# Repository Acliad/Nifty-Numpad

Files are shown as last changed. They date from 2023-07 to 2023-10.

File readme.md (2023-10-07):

Nifty Numpad is a full sized numpad with an extra row and two extra columns of macro keys. It was created because I wanted a companion to my TKL keyboard for work. My main workflow involves heavy use of ECAD programs, so the design was tailored for that, but it is generic enough to be nice for many workflows! 

The main features are:
- Full sized numpad with row of macro/function keys on the top
- Two extra columns of macro keys
- Cherry MX style socketed switches
- Backlit keys
- 3D printable case (FDM or resin)

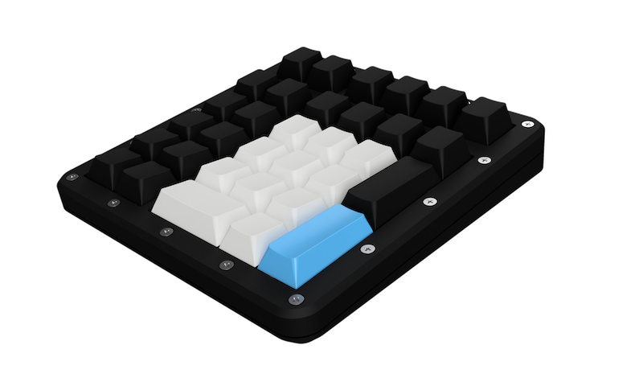
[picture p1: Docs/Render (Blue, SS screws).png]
render Render of Nifty Numpad


# Contents
- [Contents](#contents)
- [Building One](#building-one)
  - [1. PCB Assembly](#1-pcb-assembly)
  - [2. 3D Printed Case](#2-3d-printed-case)
  - [3. Switch Mounting Plate](#3-switch-mounting-plate)
  - [4. Switches/Keycaps](#4-switcheskeycaps)
  - [5. Software](#5-software)
- [TODO](#todo)
  - [Software](#software)
- [Changelog](#changelog)
  - [PCB](#pcb)
    - [Rev 1](#rev-1)
  - [Software](#software-1)
  - [Mechanical](#mechanical)

# Building One
All of the files needed to build this numpad are in this repo (with software as a submodule and in the main QMK repo). The total BOM cost will be somewhere around $65-$85 shipped, but depends heavily on where and how you source things like switches, keycaps, plate, etc. For example, I bought 120x switches, but if you could get 33 switches for cheaper, you might save ~$10. 

## 1. PCB Assembly
The most difficult part of the build is soldering the RP2040 (microcontroller used) and associated components. It is highly recommended that you have the PCBs assembled. The files are in this repo for getting the PCB assembled through JLC PCB. You may save some money by soldering some of the components yourself (especially the sockets and LEDs). However, if you just love to solder this can be done with a stencil and plenty of time. I should know 🥲

You can choose to omit the LEDs if you're not into that sort of thing. It'll save you a few bucks. 

Parts marked as (DNF) in the BOM are not meant to be populated. If you want easy debugging for software development, you can populate R103, SW101, and SW102.

To have the PCB assembled:
1. Upload the gerber files from PCB/Main PCB/production/Nifty_Numpad.zip to JLC PCB.
2. Check the PCB Assembly toggle on the JLC PCB order page.
   1. Choose the PCBA Type. If you want JLC to solder the LEDs and sockets for you, you need to choose Standard. Otherwise, choose economy. Economy is a bit cheaper.
3. On the PCB Assembly page, you will need to upload the bom.csv and positions.csv file from PCB/Main PCB/production/
4. On the Components Placements page, make sure all of the ICs are orientated correctly. They usually aren't by default since JLC's library orientation is generally different from KiCad's.

To Solder the PCB assembly yourself:
1. Order PCBs (I use JLC, you can use whomever you like).
2. Order a stencil (you can usually do this at the same time as the PCB).
3. Order parts (I have DigiKey PNs in the electrical BOM, but again feel free to substitute)
   - The switch sockets are not available on DigiKey. [I bought mine on Amazon](https://www.amazon.com/dp/B0BVH6M5FP?psc=1&ref=ppx_yo2ov_dt_b_product_details), but you can source them from most keyboard suppliers.
   - The LEDs come in packs of 10. You can get them from DigiKey or Adafruit, but note if you upload the BOM directly to DigiKey it will put in a quantity of 33, which is actually 330.
4. Solder it!
    - I recommend a reflow oven, but a hot air station or hot plate works too.

## 2. 3D Printed Case
This case was initially designed to be 3D printed on a resin printer, but it actually prints best on an FDM printer. There are not special instructions here. You can either print the case yourself or have it printed using a service. JLC offers printing of many varieties. This might be a good choice if you're already ordering the PCB from them.

All the screw holes are designed to be tapped by a self-tapping screw. The BOM has some recommendations for some plastic-threading screws. 

I have added a "[shadow line](https://www.youtube.com/watch?v=8dhFhU7Nl_0)" to the case outline. There's a top-case print option with and without this line. I think it helps the look a bit for FDM prints, but it's up to you. 

It helps the sound profile considerably to fill up the case with some kind of dampening material. You could use foam or pour castable silicone into the case (I used [this one](https://www.amazon.com/gp/product/B07V5FFPWC/ref=ppx_yo_dt_b_search_asin_title?ie=UTF8&psc=1)). You can (and probably should) pour the silicone directly into the case. However, I've also included a mold for this in the Mechanical folder.

## 3. Switch Mounting Plate
I used [plate-mount](https://switchandclick.com/plate-mounted-vs-pcb-mounted-keyboard/) switches on this design. You can either make your own plate or have one made for you. There's a model of the plate as well as a DXF file in the Mechanical folder. Here is some information about some options:

1. Order a plate out of FR-4 when you order the PCB
   - This is a good option if you're already ordering the PCB from JLC. You can order the plate at the same time and save on shipping. 
   - This plate is quite rigid and I've found it to work well.
2. Order or make a custom plate out of your preferred material.
    - If you have a laser cutter or CNC, you can use the DXF or step file to make a plate out of whatever material you like! Many people use plexilgass, but you could use wood or metal. 
3. Use the provided 3D model of the plate to 3D print a plate.
   - The plate works, but it's quite flimsy and makes taking all the switches off the PCB tedious

Whatever you choose to do, you should find appropriate files in the Mechanical folder.

## 4. Switches/Keycaps
The fun part! Choose your favorite Cherry MX compatible switches and pop them in. If you're using LEDs, make sure you get switches with a clear top. 

I found it difficult to source backlit keycaps that fit this build well. You might be better off using non-backlit keycaps. There are [some AliExpress sellers](https://www.aliexpress.us/item/3256801609324454.html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) who will sell portions of a keyboard at a time so you can mix and match colors. This is what I ended up doing, but I couldn't find any in a uniform profile like XDA or DSA. If you find a good source of keycaps, please share! 

If you're feeling plush, I think the numpad + icono kits of [these keycaps](https://drop.com/buy/drop-biip-mt3-extended-custom-keycap-set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) would be really nice. 

You'll also need 3x 2u plate-mount stabilizers. You can source these from most keyboard part suppliers or Ali Express.

## 5. Software
I've used [QMK](https://qmk.fm) for this build. Theere are builds for the [VIA](https://www.caniusevia.com) GUI configurator, a basic default usage, and an example for how to use the "fancy" RGB Idle mode and some tap-dance features. VIA is probably the easiest way to configure the keymap since you can configure it over a GUI, but if you're comfortable with QMK, you can do some cool customizations.

The Nifty Numpad has been merged into the main QMK repo, which you can find [here](https://github.com/qmk/qmk_firmware). My personal fork for developing the keyboard software is a submodule of this repo. You can find it [here](https://github.com/Acliad/qmk_firmware).

QMK and the build/flash process is pretty well document, so I'll leave that to the QMK community. If you have specific issues with the Nifty Numpad, feel free to message me. 

# TODO
## Software
- ~Implement VIAL for GUI remapping of buttons~
- ~Add other keymaps (an actual default and rename current to Cadence is a good start)~
- Create visual legend for RGB settings layer

# Changelog
## PCB
### Rev 1
- Changed footprint for W25Q40CLSNIG from wide to narrow footprint to match DigiKey PN
- Changed standoff holes to 6.0mm (from 4.6mm)
- Update LED footprint
- Add WASD graphic

## Software
- Added additional keymaps: default, VIA, and example. Old default moved to "Cadence" keymap
- Cleaned up code and file structure to align with QMK standards

## Mechanical
- Updated plate to use pan head screws
- Added clearance to top piece for pan head plate mount screws
- Moved "Designed By" tag to inside numpad
- Added a silicone sound dampening mold
- Added a "[shadow line](https://www.youtube.com/watch?v=8dhFhU7Nl_0)" model

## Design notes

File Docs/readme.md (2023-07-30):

Nifty Numpad is a full sized numpad with an extra row and two extra columns of macro keys. It was created because I wanted a companion to my TKL keyboard for work. My main workflow involves heavy use of ECAD programs, so the design was tailored for that, but it is generic enough to be nice for many workflows! 

The main features are:
- Full sized numpad with row of macro/function keys on the top
- Two extra columns of macro keys
- Cherry MX style socketed switches
- Backlit keys
- 3D printable case (FDM or resin)

render Render of Nifty Numpad

# Contents
- [Contents](#contents)
- [Building One](#building-one)
  - [1. PCB Assembly](#1-pcb-assembly)
  - [2. 3D Printed Case](#2-3d-printed-case)
  - [3. Switch Mounting Plate](#3-switch-mounting-plate)
  - [4. Switches/Keycaps](#4-switcheskeycaps)
  - [5. Software](#5-software)
- [TODO](#todo)
  - [Software](#software)
- [Changelog](#changelog)
  - [PCB](#pcb)
    - [Rev 1](#rev-1)
  - [Software](#software-1)
    - [Rev 1](#rev-1-1)
  - [Mechanical](#mechanical)
    - [Rev 1](#rev-1-2)

# Building One
All of the files needed to build this numpad should be in this repo (with software as a submodule). The total BOM cost will probably be somewhere around $55-$85 shipped, but depends heavily on where and how you source things like switches, keycaps, plate, etc. For example, I bought 120x switches, which is rolled into the $75 estimate. But if you could get 33 switches for cheaper, you might save ~$10. 

## 1. PCB Assembly
The most difficult part of the build is soldering the RP2040 (microcontroller used) and associated components. It is possible to at least all the difficult components–maybe all the components–assembled by JLC PCB. At this time, however, I have not done the work to make that a one-click purchase. If you would like to contribute, that would be very welcome! 🙂

That said, if you really would like one of these but can't or don't want to do the soldering, feel free to shoot me a message. 

If you do have experience with reflow soldering (using a stencil), this shouldn't be too difficult. The RP2040 and USB-C connectors can be a little finicky, but with enough flux, anything is possible. 

To create the PCB assembly:
1. Order PCBs (I use JLC, you can use whoever you like).
2. Order a stencil (you can usually do this at the same time as the PCB).
3. Order parts (I have DigiKey PNs in the electrical BOM, but again feel free to substitute)
   - The switch sockets are not available on DigiKey. [I bought mine on Amazon](https://www.amazon.com/dp/B0BVH6M5FP?psc=1&ref=ppx_yo2ov_dt_b_product_details), but you can source them from most keyboard suppliers.
   - The LEDs come in packs of 10. You can get them from DigiKey or Adafruit, but note if you upload the BOM directly to DigiKey it will put in a quantity of 33, which is actually 330.
4. Solder it!
    - I recommend a reflow oven, but a hot air station or hot plate works too.

You can choose to omit the LEDs if you're not into that sort of thing. It'll save you a few bucks. 

Parts marked as (DNF) in the BOM are not meant to be populated. If you want easy debugging for software development, you can populate R103, SW101, and SW102.

## 2. 3D Printed Case
This case was initially designed to be 3D printed on a resin printer, but it actually prints best on an FDM printer. There are not special instructions here. You can either print the case yourself or have it printed using a service. JLC offers printing of many varieties. Might be a good choice if you're already ordering the PCB from them.

All the screw holes are designed to be tapped by a self-tapping screw. The BOM recommends some plastic-threading screws. 

I have added a "[shadow line](https://www.youtube.com/watch?v=8dhFhU7Nl_0)" to the case outline. There's a top-case print option with and without this line. I think it helps the look a bit for FDM prints, but it's up to you. 

## 3. Switch Mounting Plate
I used [plate-mount](https://switchandclick.com/plate-mounted-vs-pcb-mounted-keyboard/) switches on this design. There are services that will cut plate for you in various materials, but I've used flush mounted flat-head screws to secure the panel and the counter sink is an additional operation I don't think most services will do for you. These leaves at least three options:

1. Use the provided 3D model of the plate to 3D print a plate.
   - The plate works, but can be a bit flimsy and makes taking all the switches off the PCB tedious
2. Order or make a custom plate out of your preferred material and countersink the holes.
    - If you know what this means and are comfortable with a drill or drill press, it shouldn't be hard.
    - You could order the plate in FR4 from JLC at the same time you order the main PCB. If you end up making the KiCAD files for this, I'd love to add them to the repo. 
3. Modify the 3D model of the top piece to accommodate pan head screws. 
    - If you do this, I would love to add the file to the repo! It should be easy, I just don't have to time to print and verify right now.

Whatever you choose to do, you should find appropriate files in the Mechanical folder.

## 4. Switches/Keycaps
The fun part! Choose your favorite Cherry MX compatible switches and pop them in. If you're using LEDs, make sure you get switches with a clear top. 

I found it difficult to source backlit keycaps that fit this build well. You might be better off using non-backlit keycaps. There are [some AliExpress sellers](https://www.aliexpress.us/item/3256801609324454.html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) who will sell portions of a keyboard at a time so you can mix and match colors. This is what I ended up doing, but I couldn't find any in a uniform profile like XDA or DSA. If you find a good source of keycaps, please share! 

If you're feeling plush, I think the numpad + icono kits of [these keycaps](https://drop.com/buy/drop-biip-mt3-extended-custom-keycap-set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) would be really nice. 

You'll also need 3x 2u plate-mount stabilizers. You can source these from most keyboard part suppliers or Ali Express.

## 5. Software
I've used [QMK](https://qmk.fm) for this build. At the time of writing this, I only have one keymap that's pretty specialized to using Cadence PCB Allegro. However, it should be super easy to modify that keymap to fit your needs. I also plan on adding a better default mode and eventually implementing VIAL. Check the [TODO](#todo) list for planned updates. 

The Nifty Numpad hasn't been merged into the main QMK repo yet, so for now you can find it [here](https://github.com/Acliad/qmk_firmware). 

QMK and the build/flash process is pretty well document, so I'll leave that to the QMK community. If you have specific issues with the Nifty Numpad, feel free to message me. 

# TODO
## Software
- Implement VIAL for GUI remapping of buttons
- Add other keymaps (an actual default and rename current to Cadence is a good start)
- Create visual legend for RGB settings layer

# Changelog
## PCB
### Rev 1
- Changed footprint for W25Q40CLSNIG from wide to narrow footprint to match DigiKey PN
- Changed standoff holes to 6.0mm (from 4.6mm)
- Update LED footprint
- Add WASD graphic

## Software
### Rev 1
-

## Mechanical
### Rev 1
- Added a "[shadow line](https://www.youtube.com/watch?v=8dhFhU7Nl_0)" model

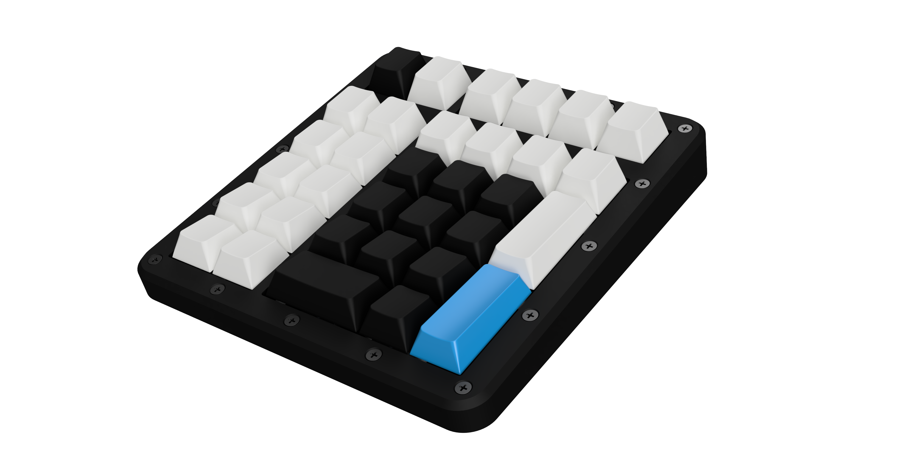
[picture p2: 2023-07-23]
Docs/Render (Black Oxide screws).png

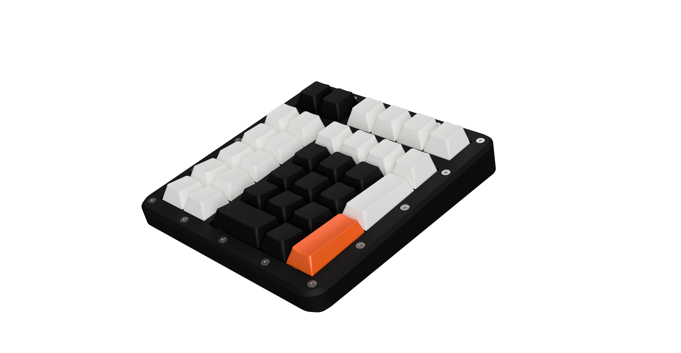
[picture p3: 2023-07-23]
Docs/Render (SS screws, orange).png

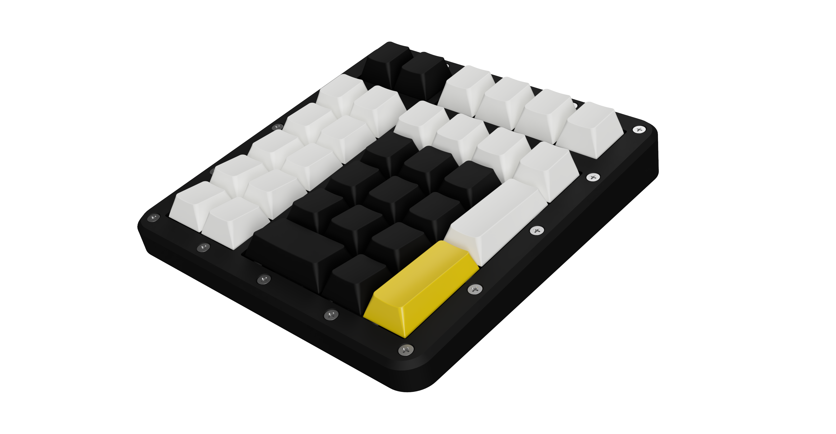
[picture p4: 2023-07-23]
Docs/Render (SS screws, yellow).png

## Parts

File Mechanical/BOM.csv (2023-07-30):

Part | Qty | Suggested Source | Comment
M2.6x10mm Plastic Tapping Screw | 16 | https://www.aliexpress.us/item/3256803049178065.html https://www.mcmaster.com/90485A432 | Use to screw top piece to base piece. You could get stainless or black depending on your preference. Note the McMaster Carr screws are actually M2.5; these are slightly smaller than the Ali Express screws and I have not tried them
M2.6x5mm Plastic Tapping Screw | 5 | https://www.aliexpress.us/item/3256803049178065.html https://www.mcmaster.com/90485A428 | Use to screw plate/PCB to base piece. You could get stainless or black depending on your preference. Note the McMaster Carr screws are actually M2.5; these are slightly smaller than the Ali Express screws and I have not tried them
Rubber Feet | 4 | https://www.mcmaster.com/95495K15/ | Attach to bottom of base
Mounting Plate | 1 | 3D Print | See the readme for more details
PCB Assembly | 1 | JLC PCB and self assembly | See the electrical BOM and readme for more details
Switches | 33 | Microcenter Any keyboard part supplier | Use your favorite Cherry MX compatible switches. Microcenter tends to have good prices on these if you have a local store. Make sure you get ones with a clear top if you're using the LEDs!
Keycaps | 33 | https://www.aliexpress.us/item/3256801609324454.html | You’ll have more options if you don’t look for backlit keycaps, but choose what you want!
2u Plate-mount Stabilizers | 3 | https://www.aliexpress.us/item/3256801595153884.html?curPageLogUid=UpkIp3myNO7D https://www.amazon.com/dp/B0978PWJG9?psc=1&ref=ppx_yo2ov_dt_b_product_details | These are also pretty generic and available from most keyboard parts suppliers. This design uses plate-mount stabs without the nubs on the bottom (but you can always clip these off).

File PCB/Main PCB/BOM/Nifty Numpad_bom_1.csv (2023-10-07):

References | Value | LCSC | DigiKey PN | Quantity Per PCB | Footprint | Datasheet
C118-C119 | 27pF | C107045 | 1276-2247-1-ND | 2 | C_0603_1608Metric | ~
C104-C114, C117, C201-C233 | 100nF | C14663 | 1276-1006-1-ND | 45 | C_0603_1608Metric | ~
C102-C103, C115-C116 | 1uF | C15849 | 1276-6524-1-ND | 4 | C_0603_1608Metric | ~
C101 | 10uF | C19702 | 490-10475-1-ND | 1 | C_0603_1608Metric | ~
D301-D333 | 1N4148 | C444720 | 4530-1N4148WCT-ND | 33 | D_SOD-123 | https://media.digikey.com/pdf/Data%20Sheets/Anbon%20Semi%20PDFs/1N4148W.pdf
D201-D233 | SK6805MINI-E | C5149201 | 1528-4960-ND | 33 | LED_SK6812-E_3.2x2.8mm | https://cdn-shop.adafruit.com/product-files/4960/4960_SK6812MINI-E_REV02_EN.pdf
J101 | SWD | C492404 | 2057-PH1-05-UA-ND | 1 (DNF) | PinHeader_1x05_P2.54mm_Vertical | ~
J103 | UART | C2691448 | 2057-PH1-04-UA-ND | 1 (DNF) | PinHeader_1x04_P2.54mm_Vertical | ~
J102 | USB-C | C2927038 | 2073-USB4105-GF-A-060CT-ND | 1 | USB_C_Receptacle_GCT_USB4105-GF-A-060 | https://www.usb.org/sites/default/files/documents/usb_type-c.zip
R105-R106 | 27 | C25190 | CR0603-FX-27R0ELFCT-ND | 2 | R_0603_1608Metric | ~
R104 | 330 | C23138 | CR0603-FX-3300ELFCT-ND | 1 | R_0603_1608Metric | ~
R103 | 1k | C21190 | RNCP0603FTD1K00CT-ND | 1 (DNF) | R_0603_1608Metric | ~
R108 | 1k | C21190 | RNCP0603FTD1K00CT-ND | 1 | R_0603_1608Metric | ~
R101-R102 | 5.1k | C23186 | CR0603-FX-5101ELFCT-ND | 2 | R_0603_1608Metric | ~
R107 | 10k | C25804 | RNCP0603FTD1K00CT-ND | 1 | R_0603_1608Metric | ~
SW301-SW317, SW319-SW328, SW330-SW331, SW333 | PG1511 | C5156480 |  | 30 | SW_Hotswap_Kailh_MX_1.00u | https://www.kailhswitch.com/Content/upload/pdf/202215927/CPG151101S11-16.pdf?rnd=543
SW318, SW329 | PG1511 | C5156480 |  | 2 | SW_Hotswap_Kailh_MX_2.00u_90deg | https://www.kailhswitch.com/Content/upload/pdf/202215927/CPG151101S11-16.pdf?rnd=543
SW332 | PG1511 | C5156480 |  | 1 | SW_Hotswap_Kailh_MX_2.00u | https://www.kailhswitch.com/Content/upload/pdf/202215927/CPG151101S11-16.pdf?rnd=543
SW101-SW102 | PTS636 SL43 SMTR LFS | C2800576 | CKN12309-1-ND | 2 (DNF) | SW-PUSH-6x3.5mm_CK-PTS636SL43x_HandSolder | https://www.ckswitches.com/media/2779/pts636.pdf
U101 | 3.3V | C431682 | 576-3215-1-ND | 1 | SOT-353_SC-70-5 | http://ww1.microchip.com/downloads/en/DeviceDoc/mic5365.pdf
U102 | CM1213A−02Sx | C5359995 | CM1213A-02SROSCT-ND | 1 | SOT-143 | https://www.onsemi.com/pdf/datasheet/cm1213a-d.pdf
U104 | RP2040 | C2040 | 2648-SC0914(13)CT-ND | 1 | QFN-56-1EP_7x7mm_P0.4mm_EP3.2x3.2mm | https://datasheets.raspberrypi.com/rp2040/rp2040-datasheet.pdf
U103 | SN74LVC1T45DCK | C9382 | 31-74LVC1T45DW-7CT-ND | 1 | SOT-363_SC-70-6 | http://www.ti.com/lit/ds/symlink/sn74lvc1t45.pdf
U105 | W25Q40CLSNIG | C2641149 | W25Q40CLSNIG-ND | 1 | SOIC-8_3.9x4.9mm_P1.27mm | http://www.winbond.com/resource-files/w25q32jv%20revg%2003272018%20plus.pdf
Y101 | ABLS-12.000MHZ-B4-T | C596818 | 535-10218-1-ND | 1 | Crystal_SMD_HC49-SD | https://abracon.com/Resonators/ABLS.pdf

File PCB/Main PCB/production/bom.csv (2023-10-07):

Designator | Footprint | Quantity | Value | LCSC Part #
C101 | 0603 | 1 | 10uF | C19702
C102, C103, C115, C116 | 0603 | 4 | 1uF | C15849
C104, C105, C106, C107, C108, C109, C110, C111, C112, C113, C114, C117, C201, C202, C203, C204, C205, C206, C207, C208, C209, C210, C211, C212, C213, C214, C215, C216, C217, C218, C219, C220, C221, C222, C223, C224, C225, C226, C227, C228, C229, C230, C231, C232, C233 | 0603 | 45 | 100nF | C14663
C118, C119 | 0603 | 2 | 27pF | C107045
D201, D202, D203, D204, D205, D206, D207, D208, D209, D210, D211, D212, D213, D214, D215, D216, D217, D218, D219, D220, D221, D222, D223, D224, D225, D226, D227, D228, D229, D230, D231, D232, D233 | LED_SK6812MINI-E_3.2x2.8mm | 33 | SK6812MINI-E | C5149201
D301, D302, D303, D304, D305, D306, D307, D308, D309, D310, D311, D312, D313, D314, D315, D316, D317, D318, D319, D320, D321, D322, D323, D324, D325, D326, D327, D328, D329, D330, D331, D332, D333 | D_SOD-123 | 33 | 1N4148 | C444720
J101 | PinHeader_1x05_P2.54mm_Vertical | 1 | SWD | DNP
J102 | USB_C_Receptacle_GCT_USB4105-GF-A-060 | 1 | USB-C | C2927038
J103 | PinHeader_1x04_P2.54mm_Vertical | 1 | UART | DNP
R101, R102 | 0603 | 2 | 5.1k | C23186
R103 | 0603 | 1 | 1k | DNP
R104 | 0603 | 1 | 330 | C23138
R105, R106 | 0603 | 2 | 27 | C25190
R107 | 0603 | 1 | 10k | C25804
R108 | 0603 | 1 | 1k | C21190
SW101, SW102 | SW-PUSH-6x3.5mm_CK-PTS636SL43x_HandSolder | 2 | PTS636 SL43 SMTR LFS | DNP
SW301, SW302, SW303, SW304, SW305, SW306, SW307, SW308, SW309, SW310, SW311, SW312, SW313, SW314, SW315, SW316, SW317, SW319, SW320, SW321, SW322, SW323, SW324, SW325, SW326, SW327, SW328, SW330, SW331, SW333 | SW_Hotswap_Kailh_MX_1.00u | 30 | PG1511 | C5156480
SW318, SW329 | SW_Hotswap_Kailh_MX_2.00u_90deg | 2 | PG1511 | C5156480
SW332 | SW_Hotswap_Kailh_MX_2.00u | 1 | PG1511 | C5156480
U101 | SOT-353_SC-70-5 | 1 | 3.3V | C431682
U102 | SOT-143 | 1 | CM1213A−02Sx | C5359995
U103 | SOT-363_SC-70-6 | 1 | SN74LVC1T45DCK | C9382
U104 | QFN-56-1EP_7x7mm_P0.4mm_EP3.2x3.2mm | 1 | RP2040 | C2040
U105 | SOIC-8_3.9x4.9mm_P1.27mm | 1 | W25Q40CLSNIG | C2641149
Y101 | Crystal_SMD_HC49-SD | 1 | ABLS-12.000MHZ-B4-T | C596818

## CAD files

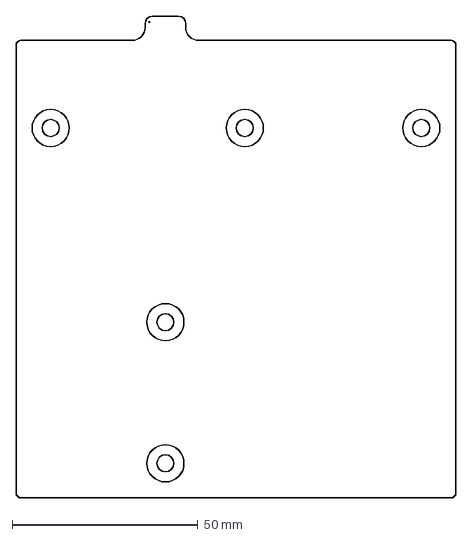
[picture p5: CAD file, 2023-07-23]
Mechanical/DXFs/PCB Outline.dxf
118.3 x 129.6 mm

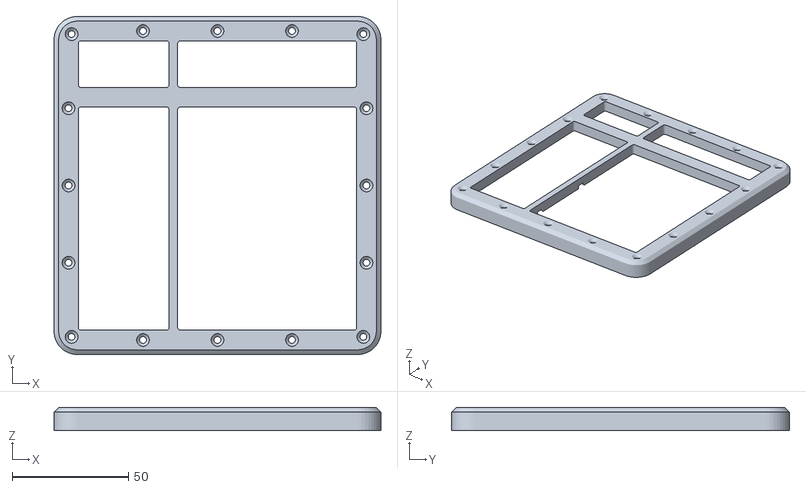
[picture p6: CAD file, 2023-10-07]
Mechanical/Meshes/Top_noShadowLine.stl
140.8 x 145.5 x 10.0

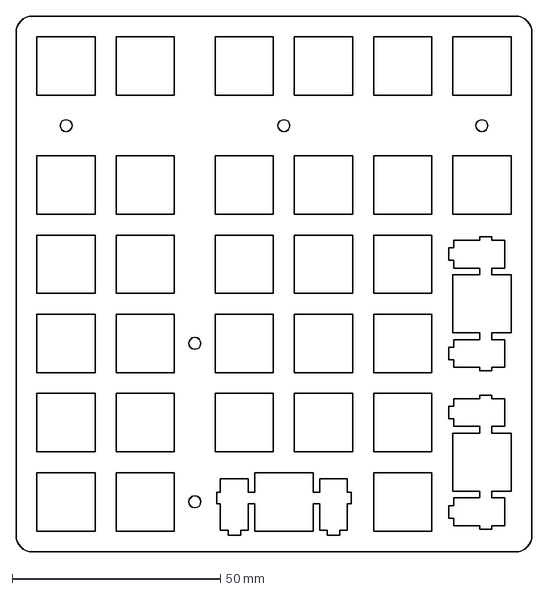
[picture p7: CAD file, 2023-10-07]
Mechanical/Plate Drawing.dxf
123.8 x 128.5 mm

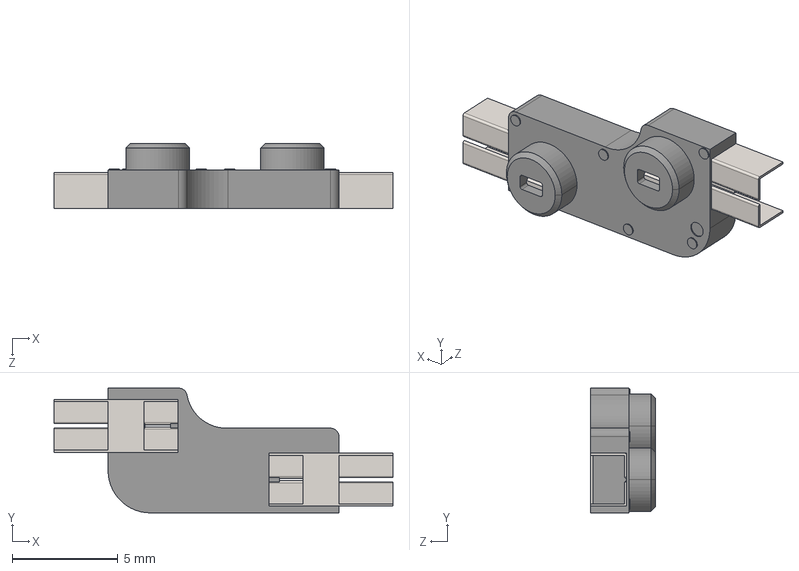
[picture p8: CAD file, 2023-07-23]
Mechanical/Solid/Kailh Hotswap MX.step
16.0 x 5.89 x 3.05 mm
Kailh Hotswap MX
Kailh Hotswap MX Inlay
Kailh Hotswap MX Inlay 2

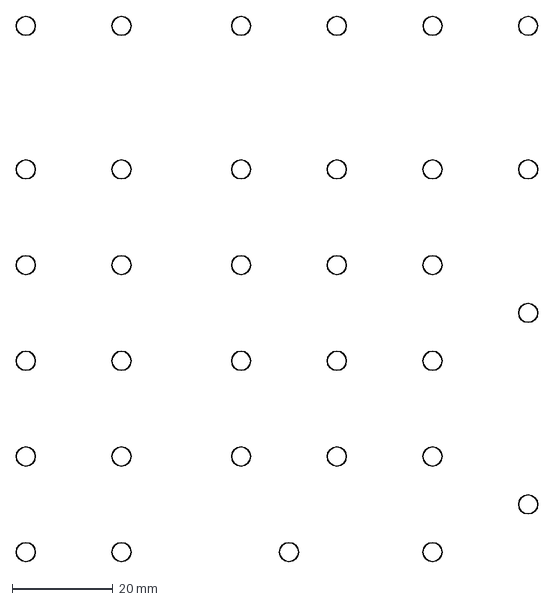
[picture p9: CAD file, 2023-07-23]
Mechanical/DXFs/PCB Switch Locations.dxf
103.6 x 108.3 mm

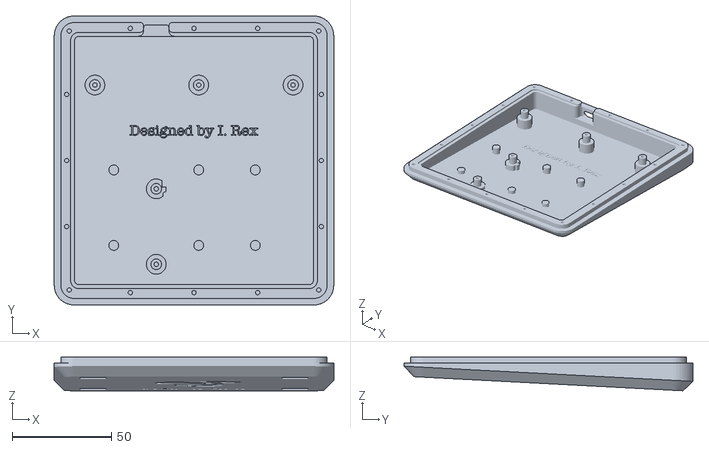
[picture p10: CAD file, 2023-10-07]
Mechanical/Meshes/Base.stl
140.8 x 145.5 x 16.9

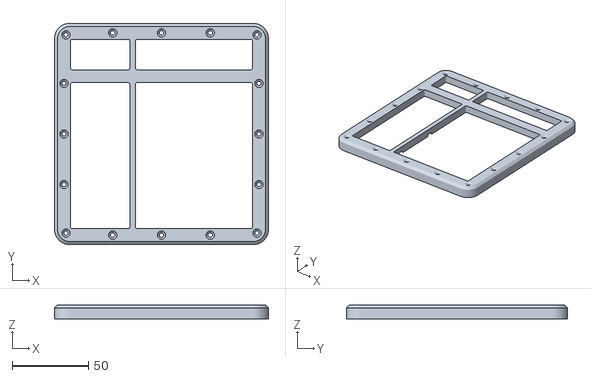
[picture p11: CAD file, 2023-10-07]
Mechanical/Meshes/Top.stl
140.8 x 145.5 x 9.30

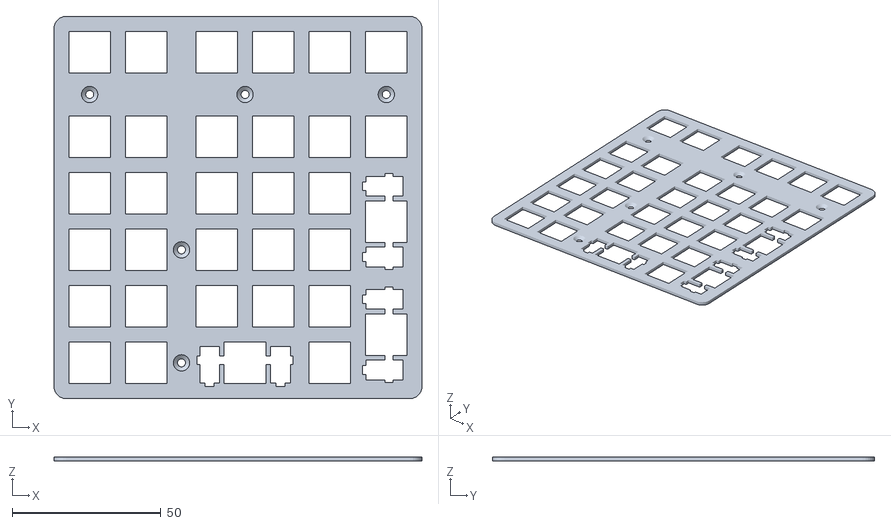
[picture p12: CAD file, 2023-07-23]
Mechanical/Meshes/Plate.stl
123.8 x 128.5 x 1.50

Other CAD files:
Mechanical/DXFs/Plate Drawing.dxf

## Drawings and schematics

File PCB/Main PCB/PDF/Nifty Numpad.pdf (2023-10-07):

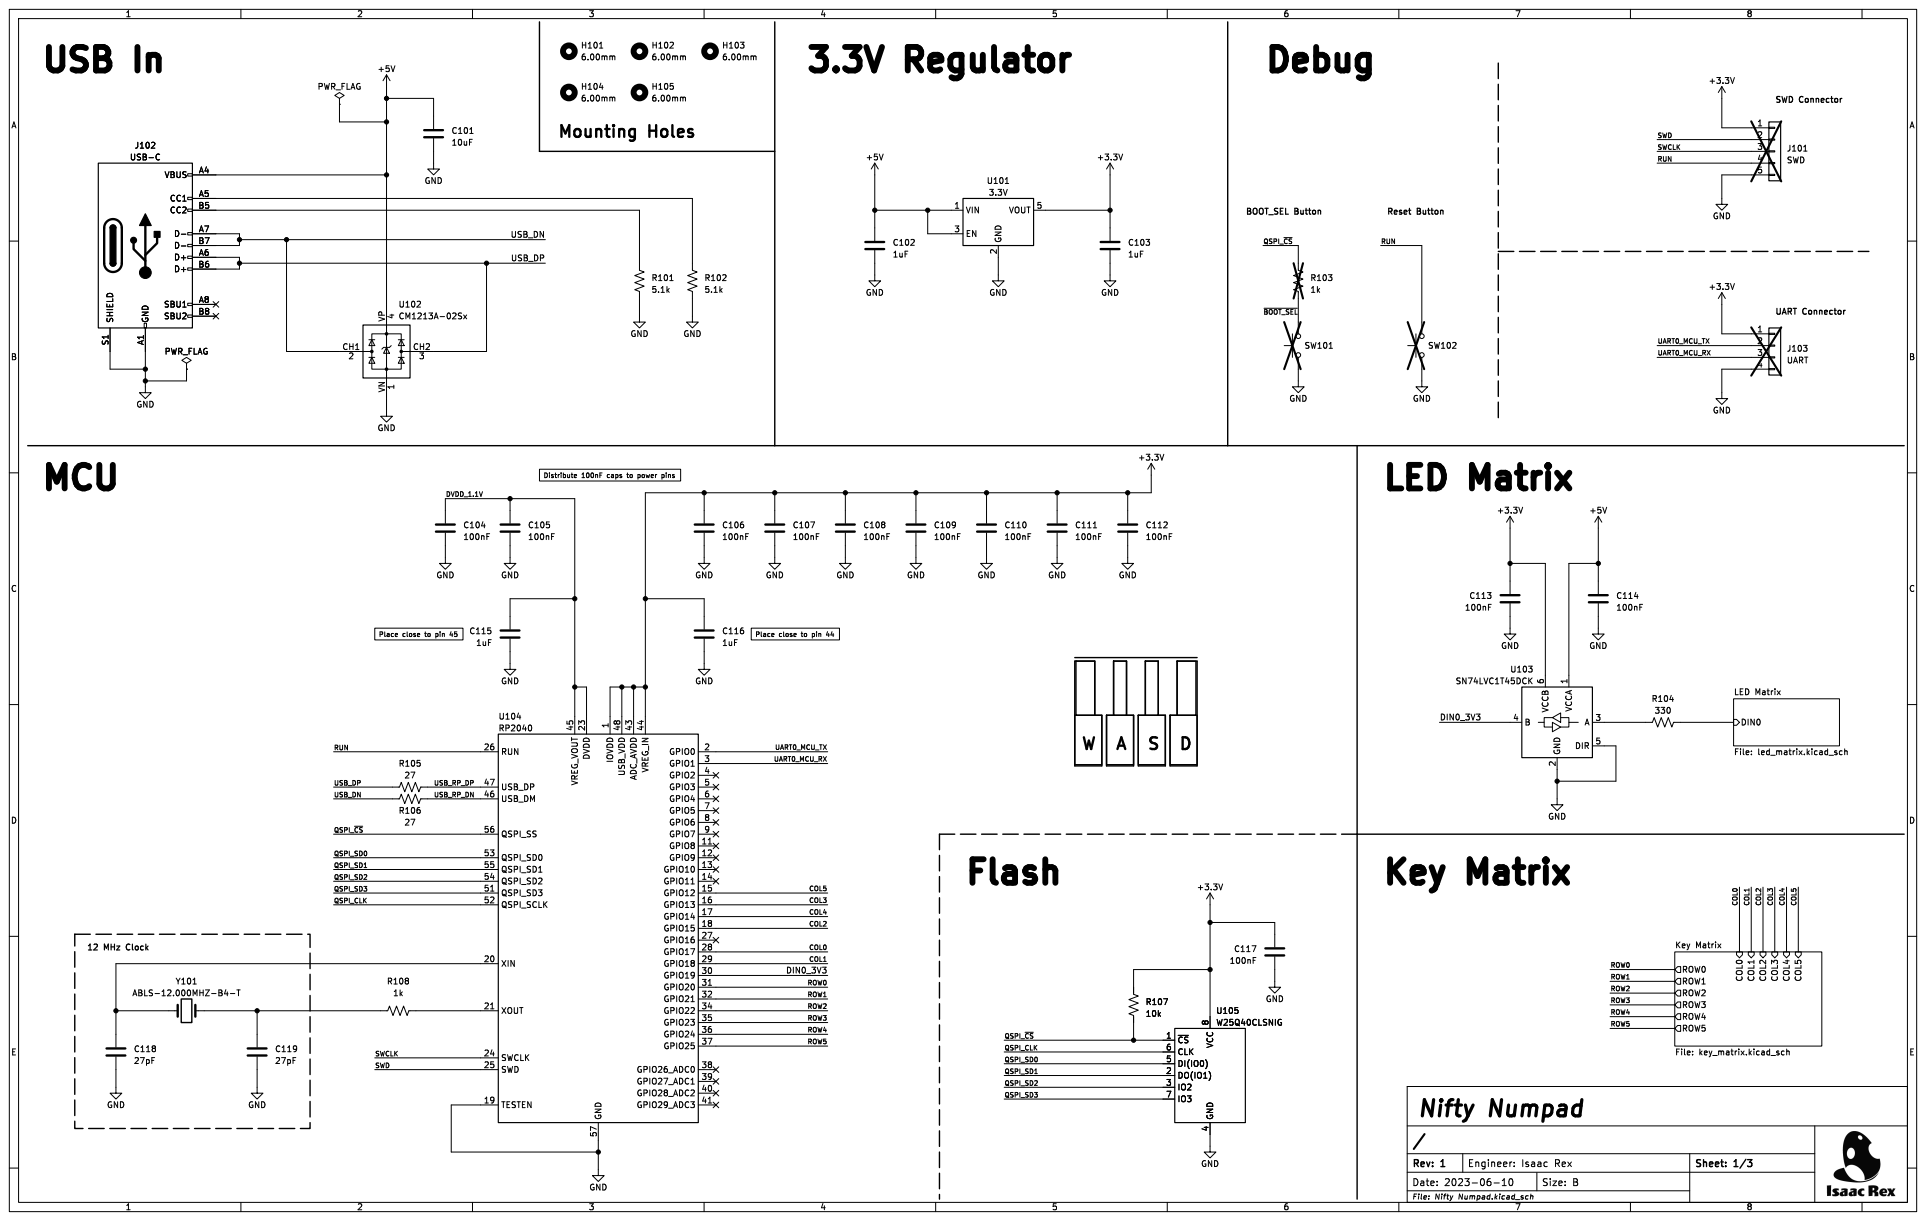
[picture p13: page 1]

1 GPIO8 11 GPIO9 12 GPIO10 13 GPIO11 14 GPIO12 15 GPIO13 16 GPIO14 17 GPIO15 18 TESTEN 19 GPIO0 2 XIN 20 XOUT 21 DVDD 23 SWCLK 24 SWD 25 RUN 26 GPIO16 27 GPIO17 28 GPIO18 29 GPIO1 3 GPIO19 30 GPIO20 31 GPIO21 32 GPIO22 34 GPIO23 35 GPIO24 36 GPIO25 37 GPIO26_ADC0 38 GPIO27_ADC1 39 GPIO2 4 GPIO28_ADC2 40 GPIO29_ADC3 41 ADC_AVDD 43 VREG_IN 44 VREG_VOUT 45 USB_DM 46 USB_DP 47 USB_VDD 48 GPIO3 5 QSPI_SD3 51 QSPI_SCLK 52 QSPI_SD0 53 QSPI_SD2 54 QSPI_SD1 55 QSPI_SS 56 GND 57 GPIO4 6 GPIO5 7 GPIO6 8 GPIO7 9 U104 RP2040 GND GND

File: Nifty Numpad.kicad_sch Nifty Numpad /

Sheet: 1/3

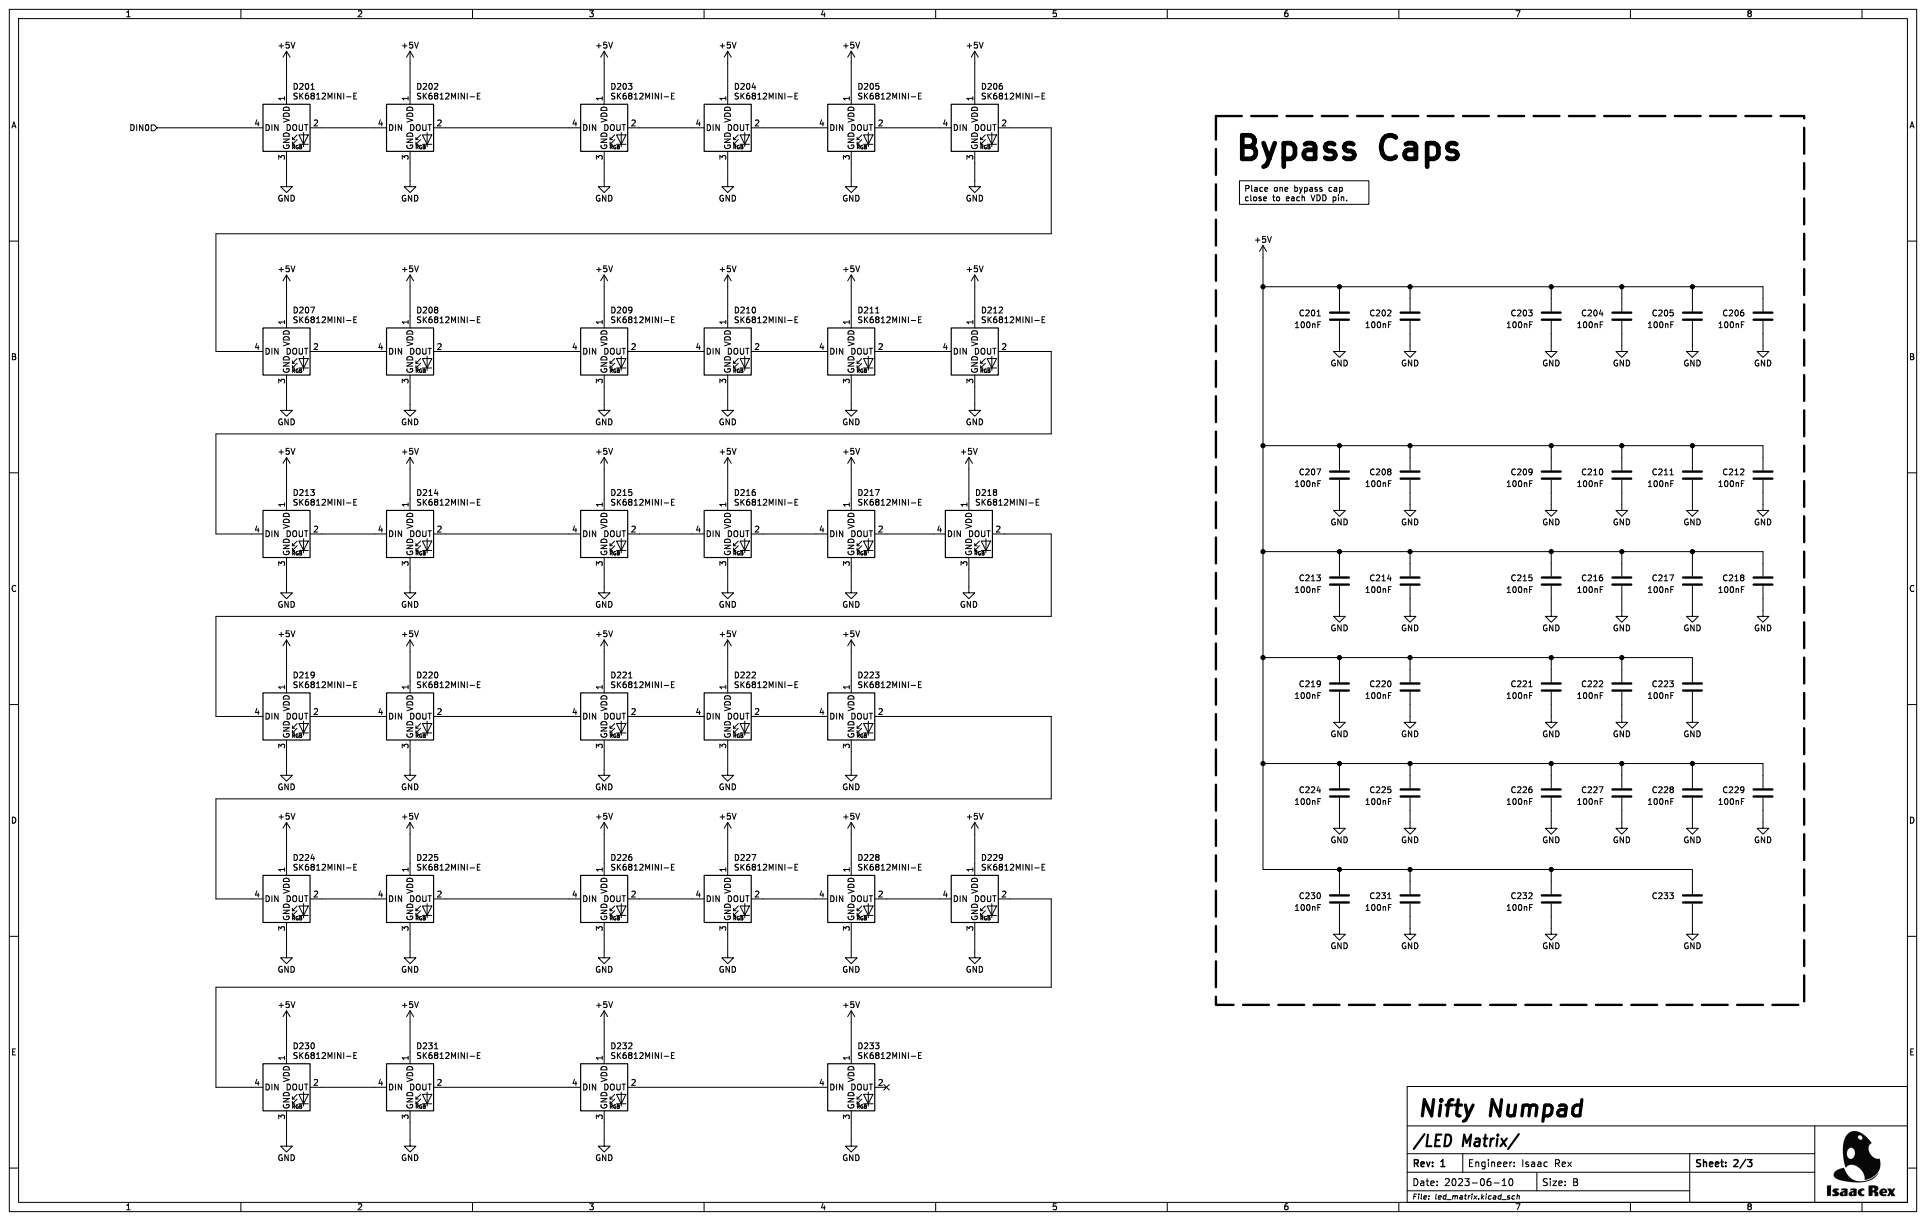
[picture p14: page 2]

Place one bypass cap
close to each VDD pin.

3 DIN 4 D229 SK6812MINI-E GND GND GND

File: led_matrix.kicad_sch Nifty Numpad /LED Matrix/

Sheet: 2/3

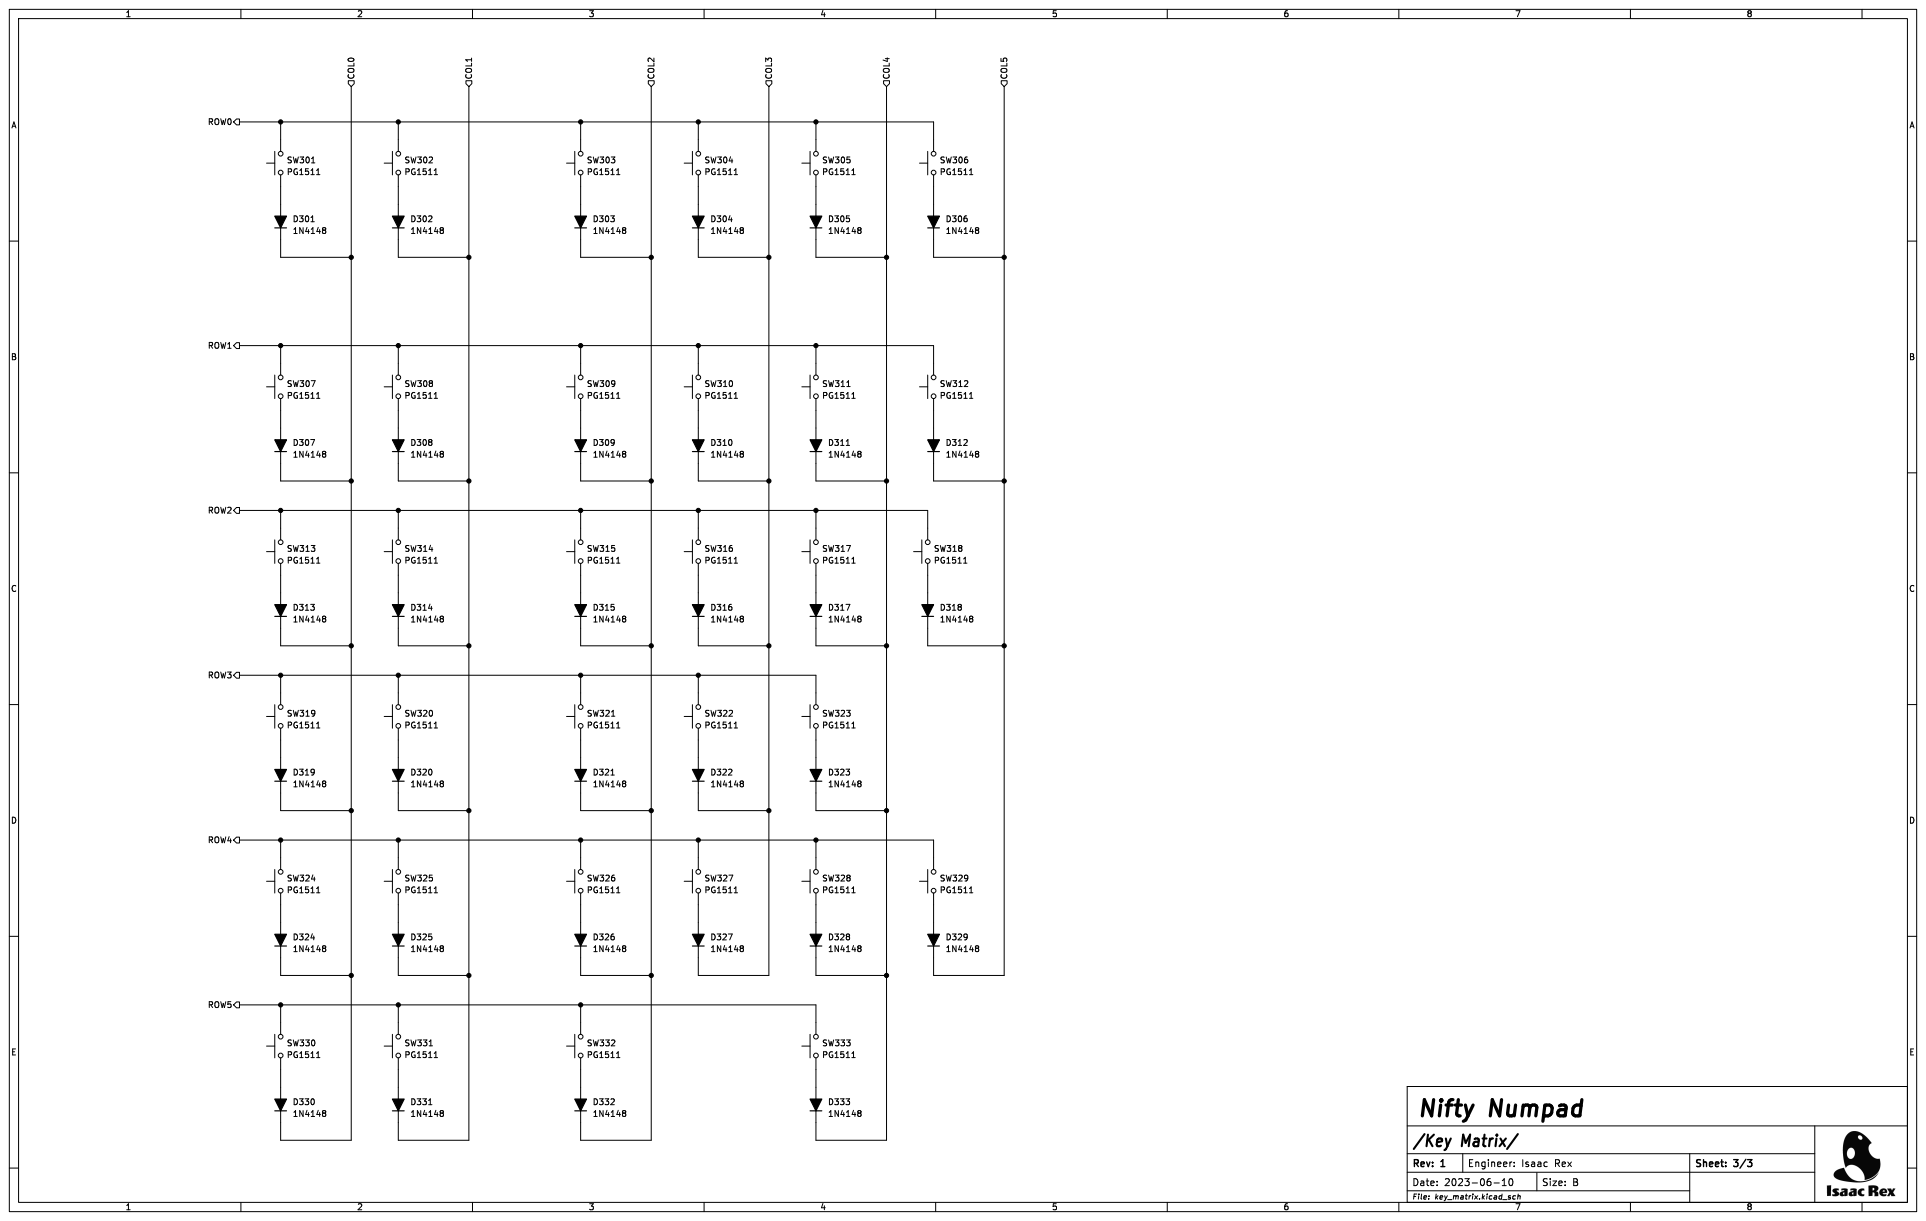
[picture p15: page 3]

File: key_matrix.kicad_sch Nifty Numpad /Key Matrix/

Sheet: 3/3

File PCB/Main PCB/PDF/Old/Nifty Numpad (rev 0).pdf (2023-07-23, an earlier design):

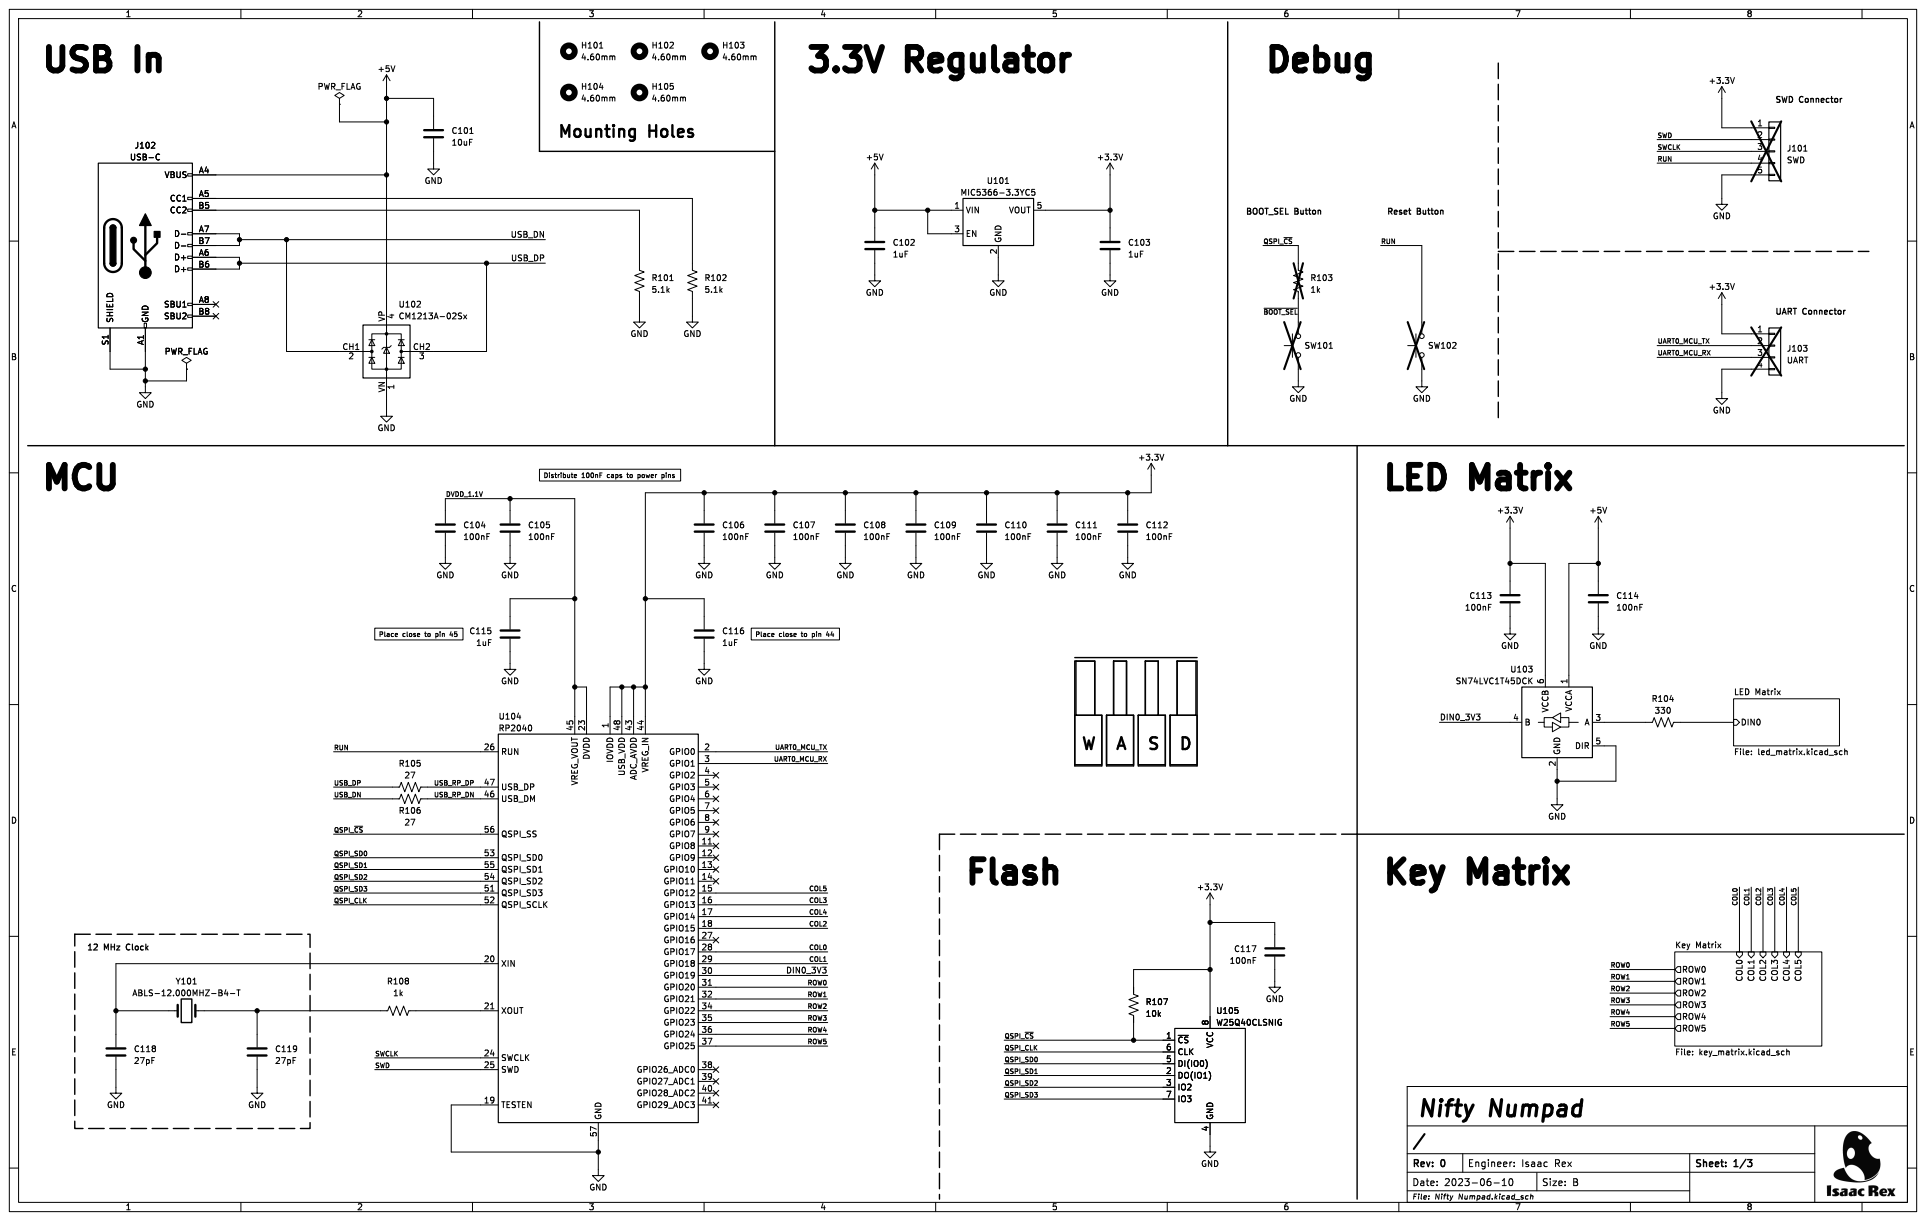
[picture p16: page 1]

UART Connector BOOT_SEL Button Debug

Reset Button LED Matrix

1 GPIO8 11 GPIO9 12 GPIO10 13 GPIO11 14 GPIO12 15 GPIO13 16 GPIO14 17 GPIO15 18 TESTEN 19 GPIO0 2 XIN 20 XOUT 21 DVDD 23 SWCLK 24 SWD 25 RUN 26 GPIO16 27 GPIO17 28 GPIO18 29 GPIO1 3 GPIO19 30 GPIO20 31 GPIO21 32 GPIO22 34 GPIO23 35 GPIO24 36 GPIO25 37 GPIO26_ADC0 38 GPIO27_ADC1 39 GPIO2 4 GPIO28_ADC2 40 GPIO29_ADC3 41 ADC_AVDD 43 VREG_IN 44 VREG_VOUT 45 USB_DM 46 USB_DP 47 USB_VDD 48 GPIO3 5 QSPI_SD3 51 QSPI_SCLK 52 QSPI_SD0 53 QSPI_SD2 54 QSPI_SD1 55 QSPI_SS 56 GND 57 GPIO4 6 GPIO5 7 GPIO6 8 GPIO7 9 U104 RP2040

File: Nifty Numpad.kicad_sch Nifty Numpad /

Sheet: 1/3

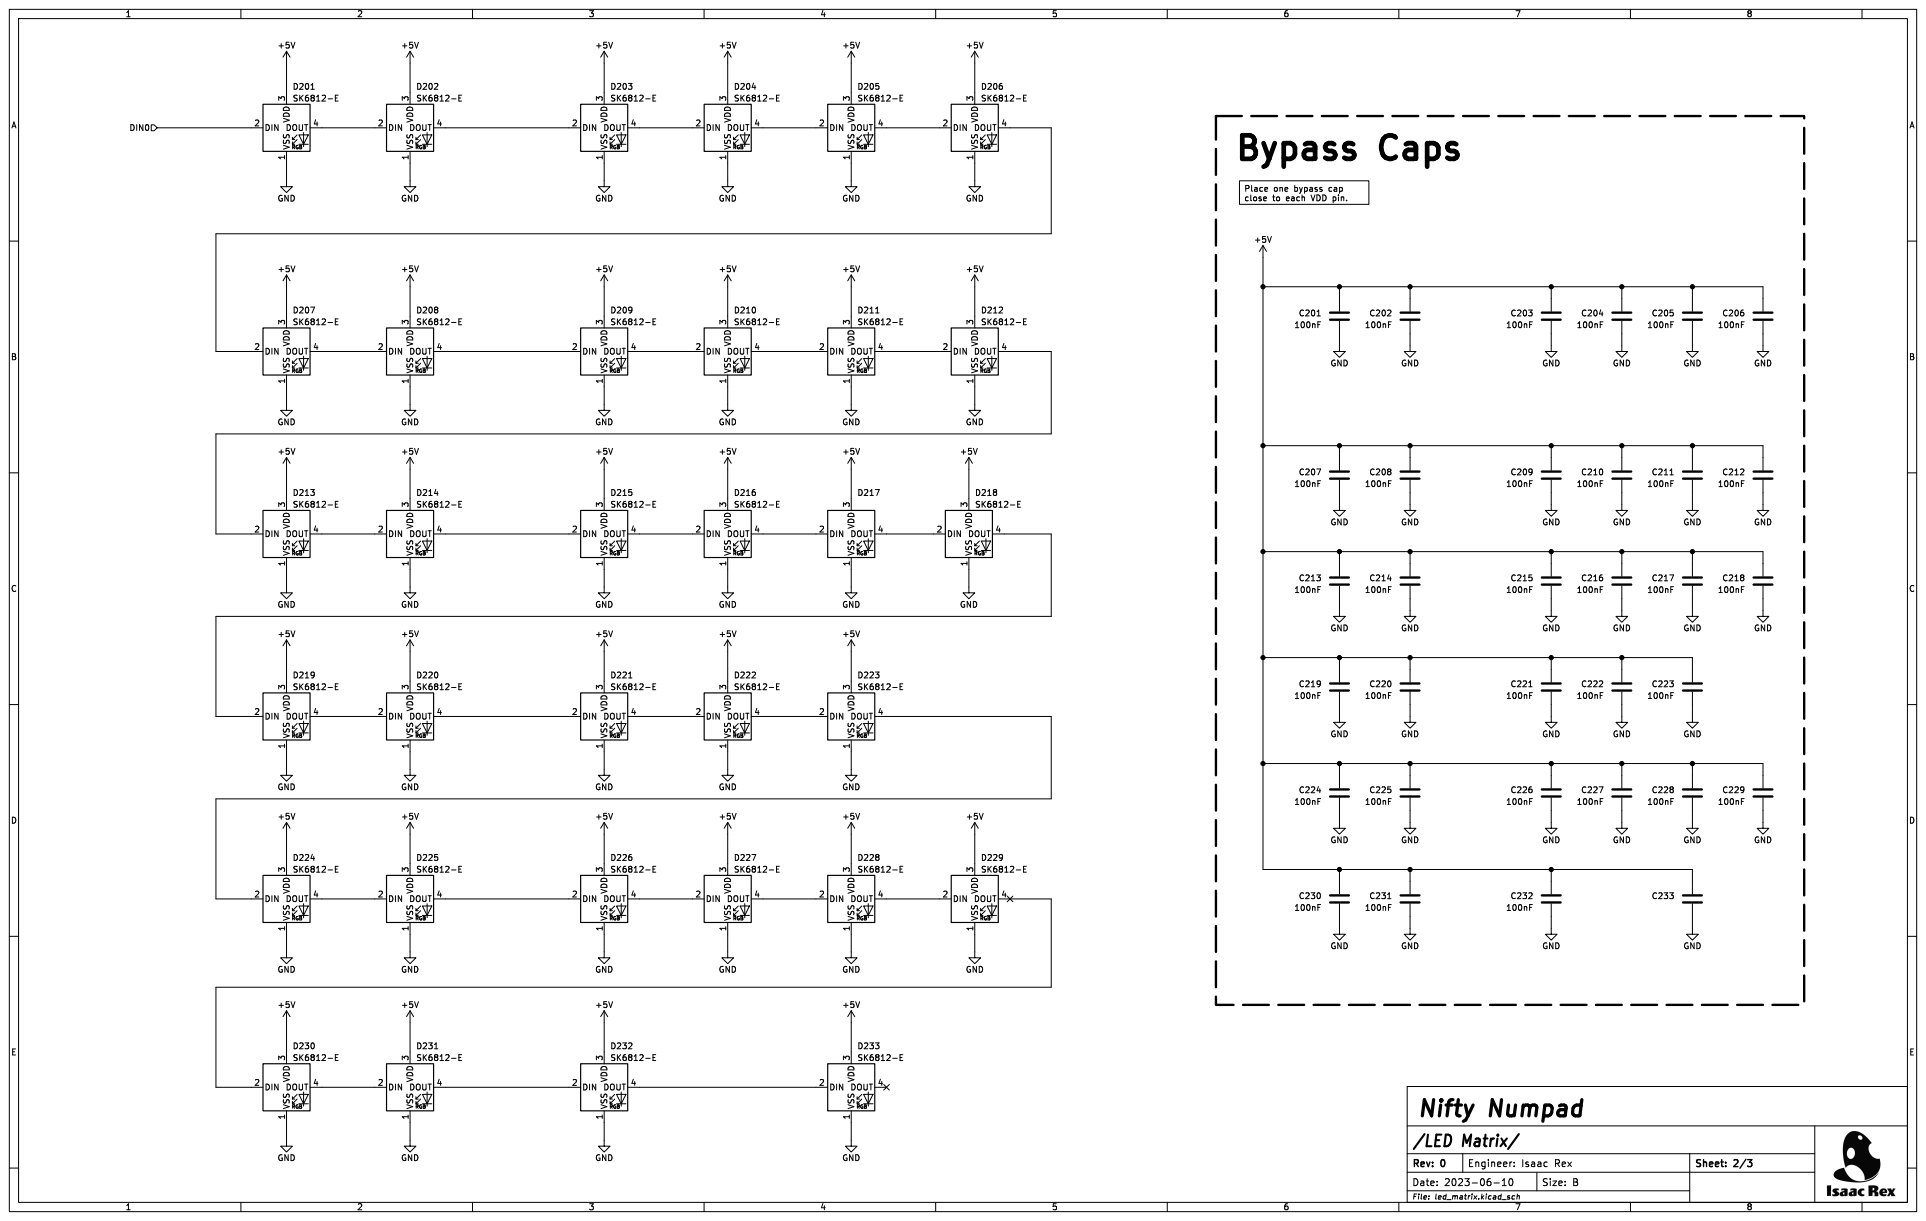
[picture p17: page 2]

3 DOUT 4 D206 SK6812-E GND GND VSS RGB 1 DIN 2 VDD

Place one bypass cap
close to each VDD pin.

3 DOUT 4 D208 SK6812-E GND GNDVSS RGB 1 DIN 2 VDD

3 DOUT 4 D212 SK6812-E GND VSS RGB 1 DIN 2 VDD

3 DOUT 4 D214 SK6812-E VSS RGB 1 DIN 2 VDD

3 DOUT 4 D231 SK6812-E GND GND GND

3 DOUT 4 D220 SK6812-E VSS RGB 1 DIN 2 VDD

3 DOUT 4 D223 SK6812-E GND VSS RGB 1 DIN 2 VDD

3 DOUT 4 D233 SK6812-E GND GND GND GND

3 DOUT 4 D225 SK6812-E GND GND GND

3 DOUT 4 D224 SK6812-E VSS RGB 1 DIN 2 VDD

3 DOUT 4 D226 SK6812-E VSS RGB 1 DIN 2 VDD

3 DOUT 4 D227 SK6812-E VSS RGB 1 DIN 2 VDD

File: led_matrix.kicad_sch Nifty Numpad /LED Matrix/

Sheet: 2/3

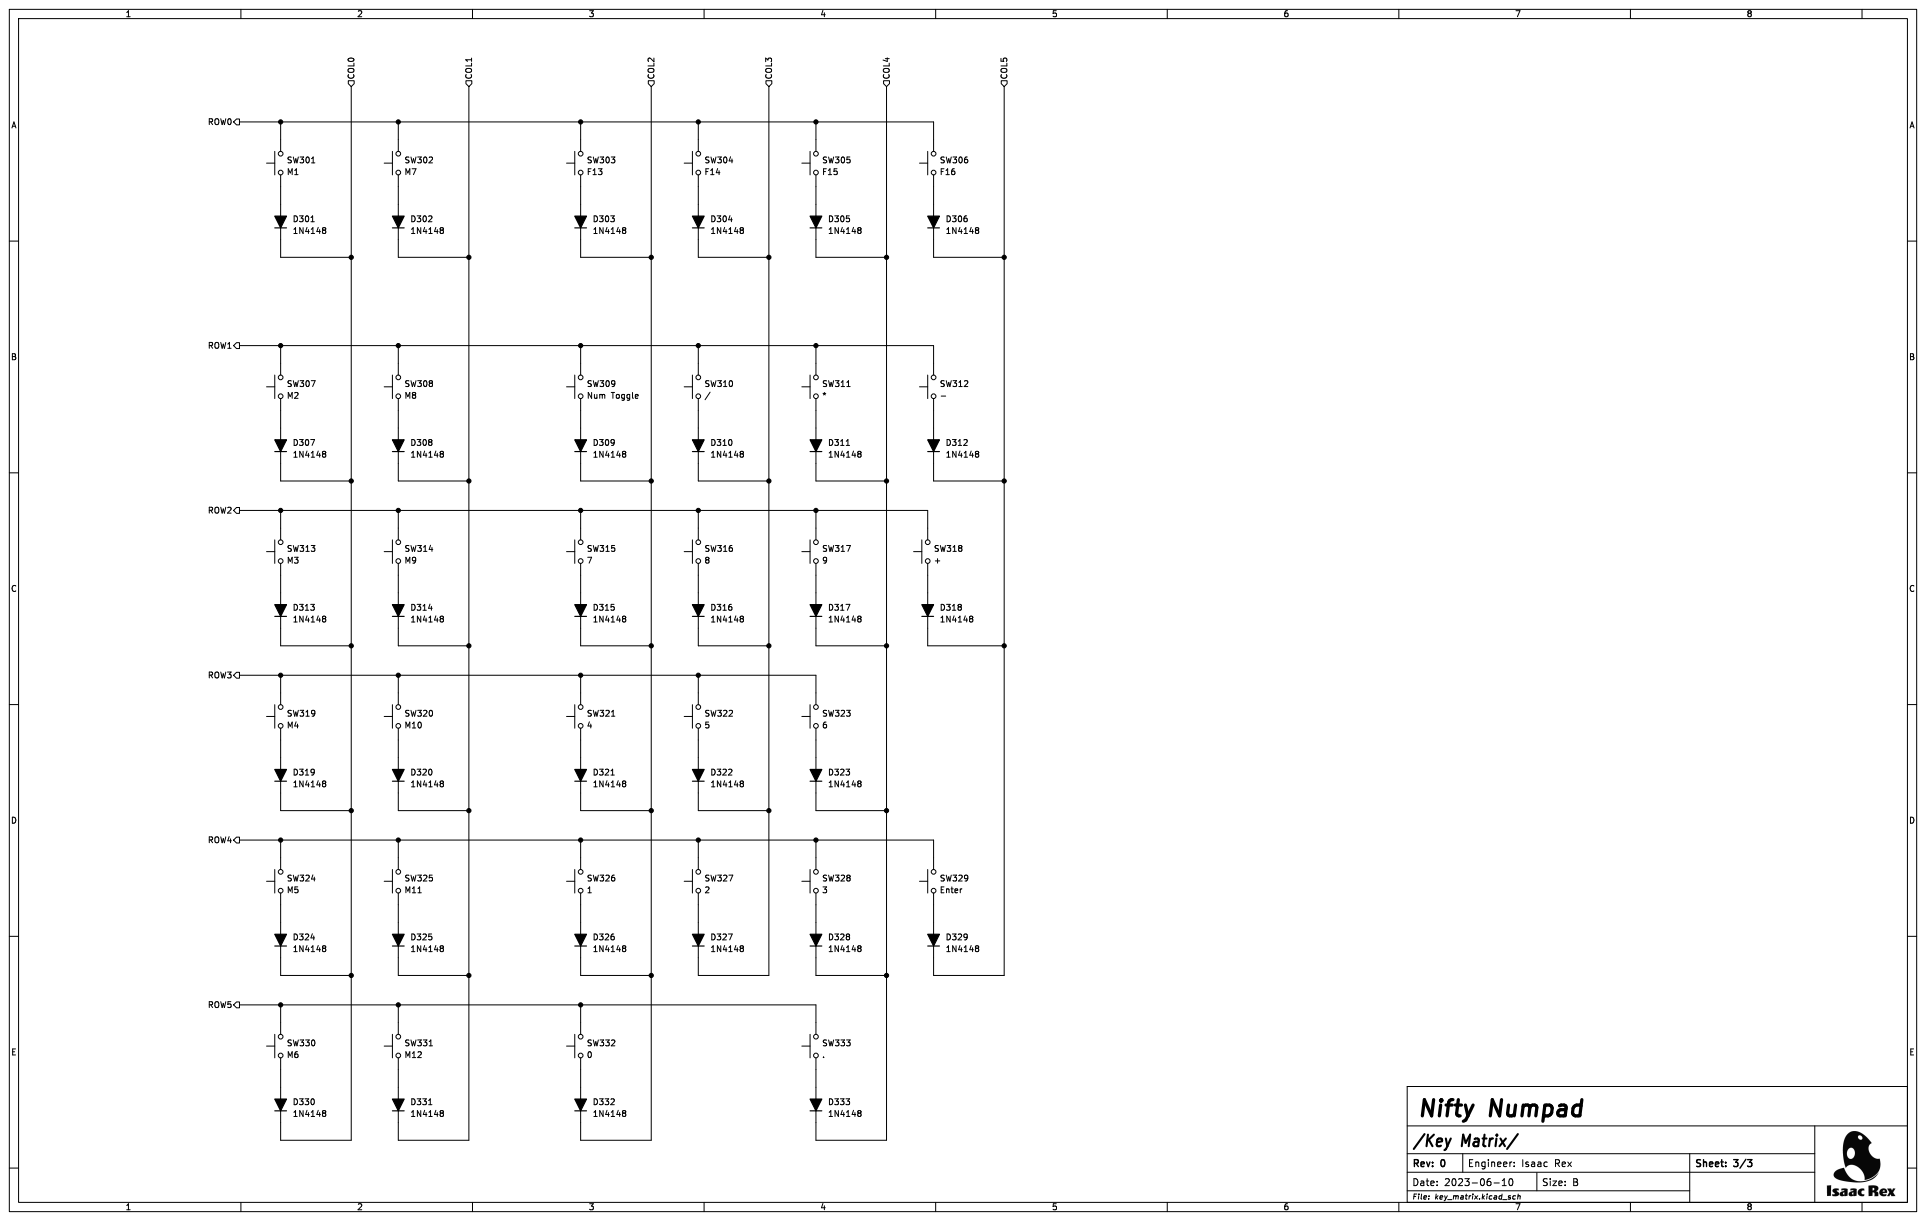
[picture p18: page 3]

File: key_matrix.kicad_sch Nifty Numpad /Key Matrix/

Sheet: 3/3

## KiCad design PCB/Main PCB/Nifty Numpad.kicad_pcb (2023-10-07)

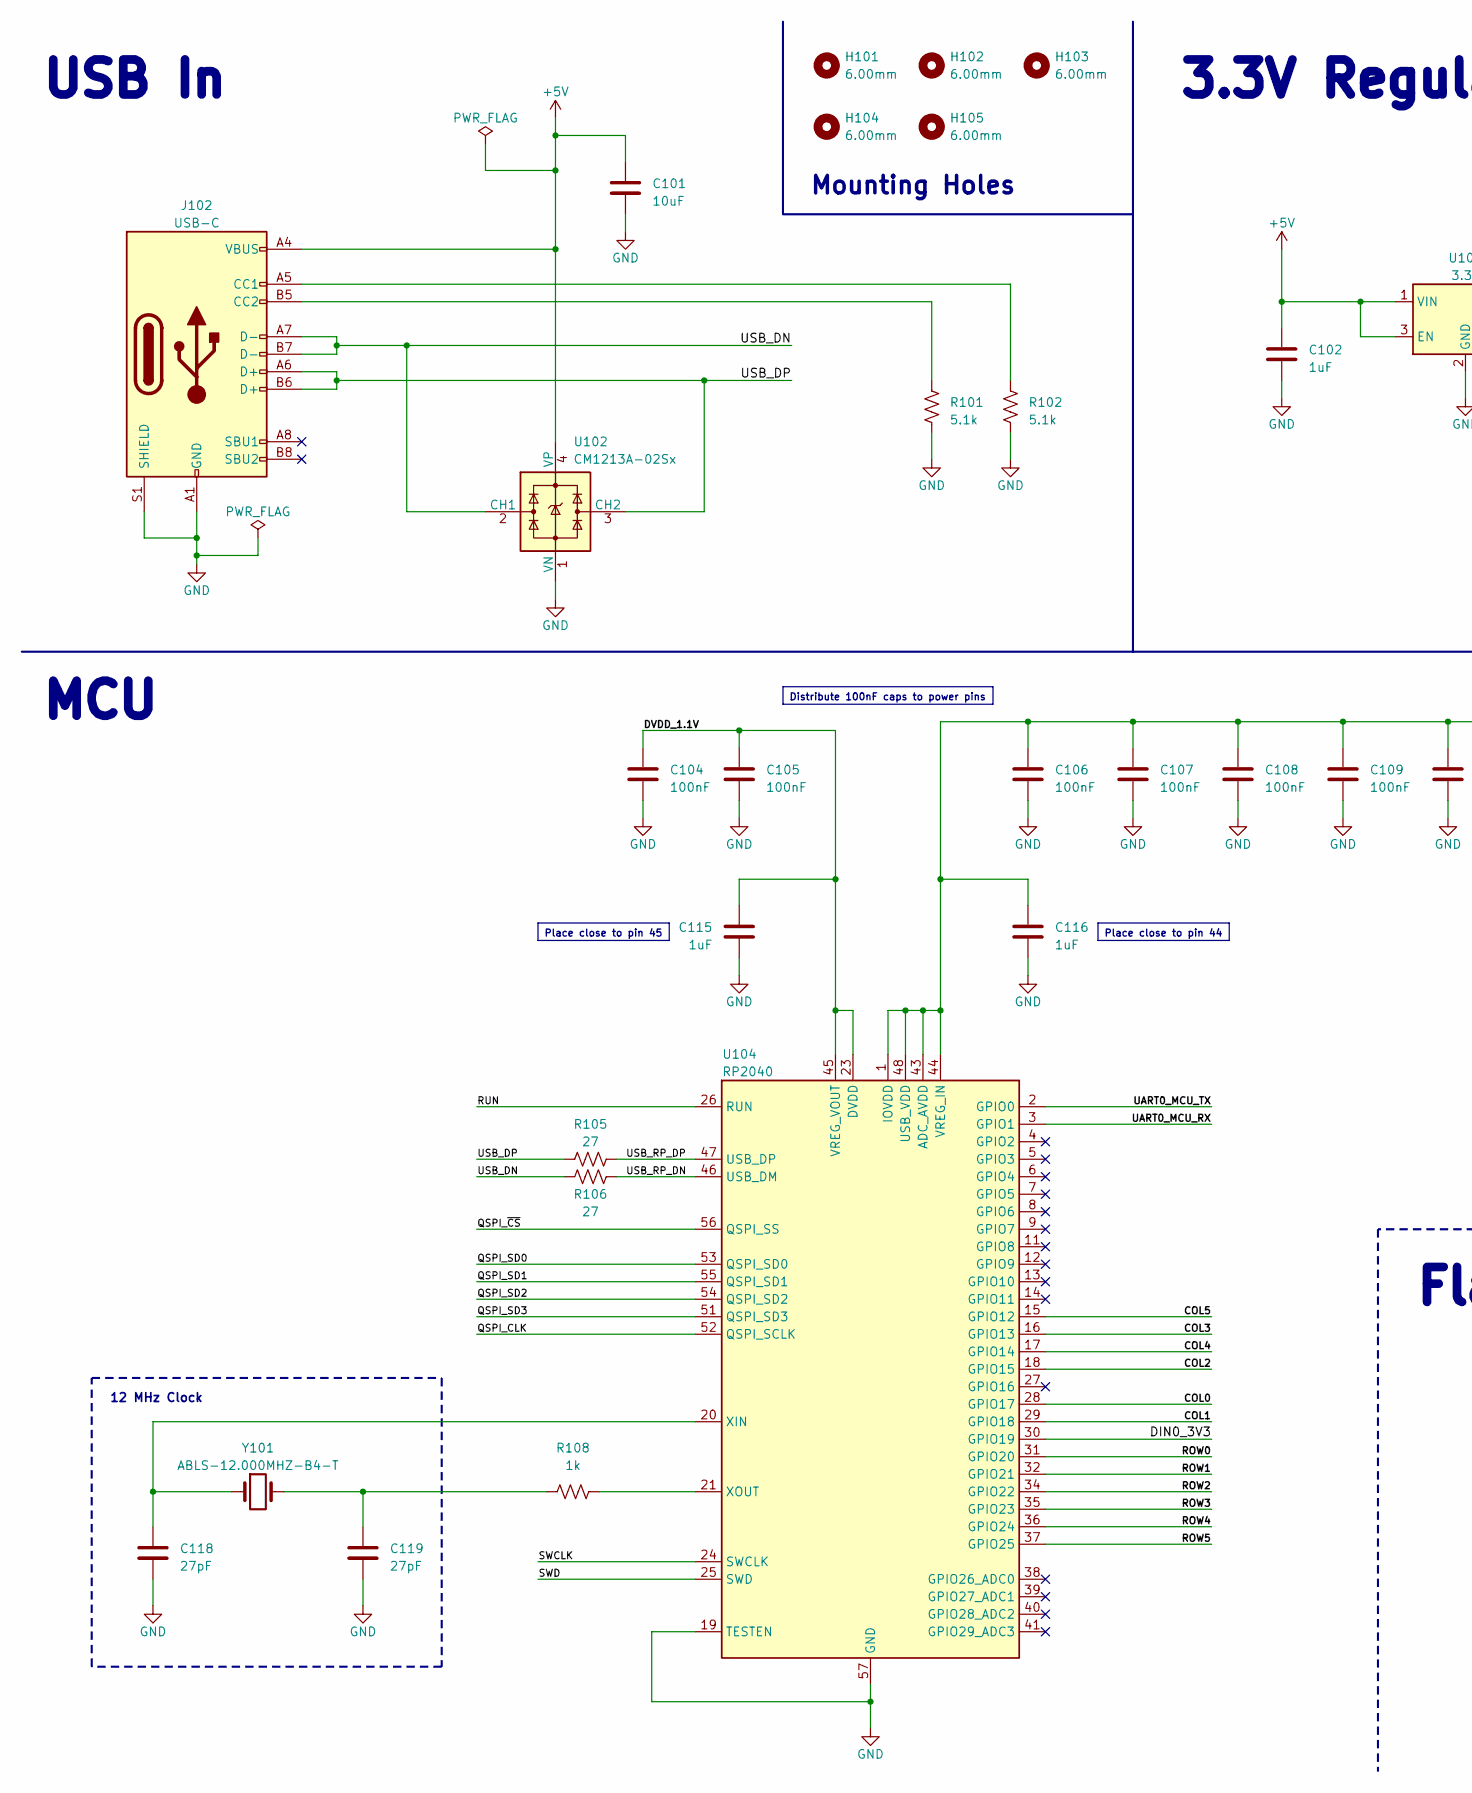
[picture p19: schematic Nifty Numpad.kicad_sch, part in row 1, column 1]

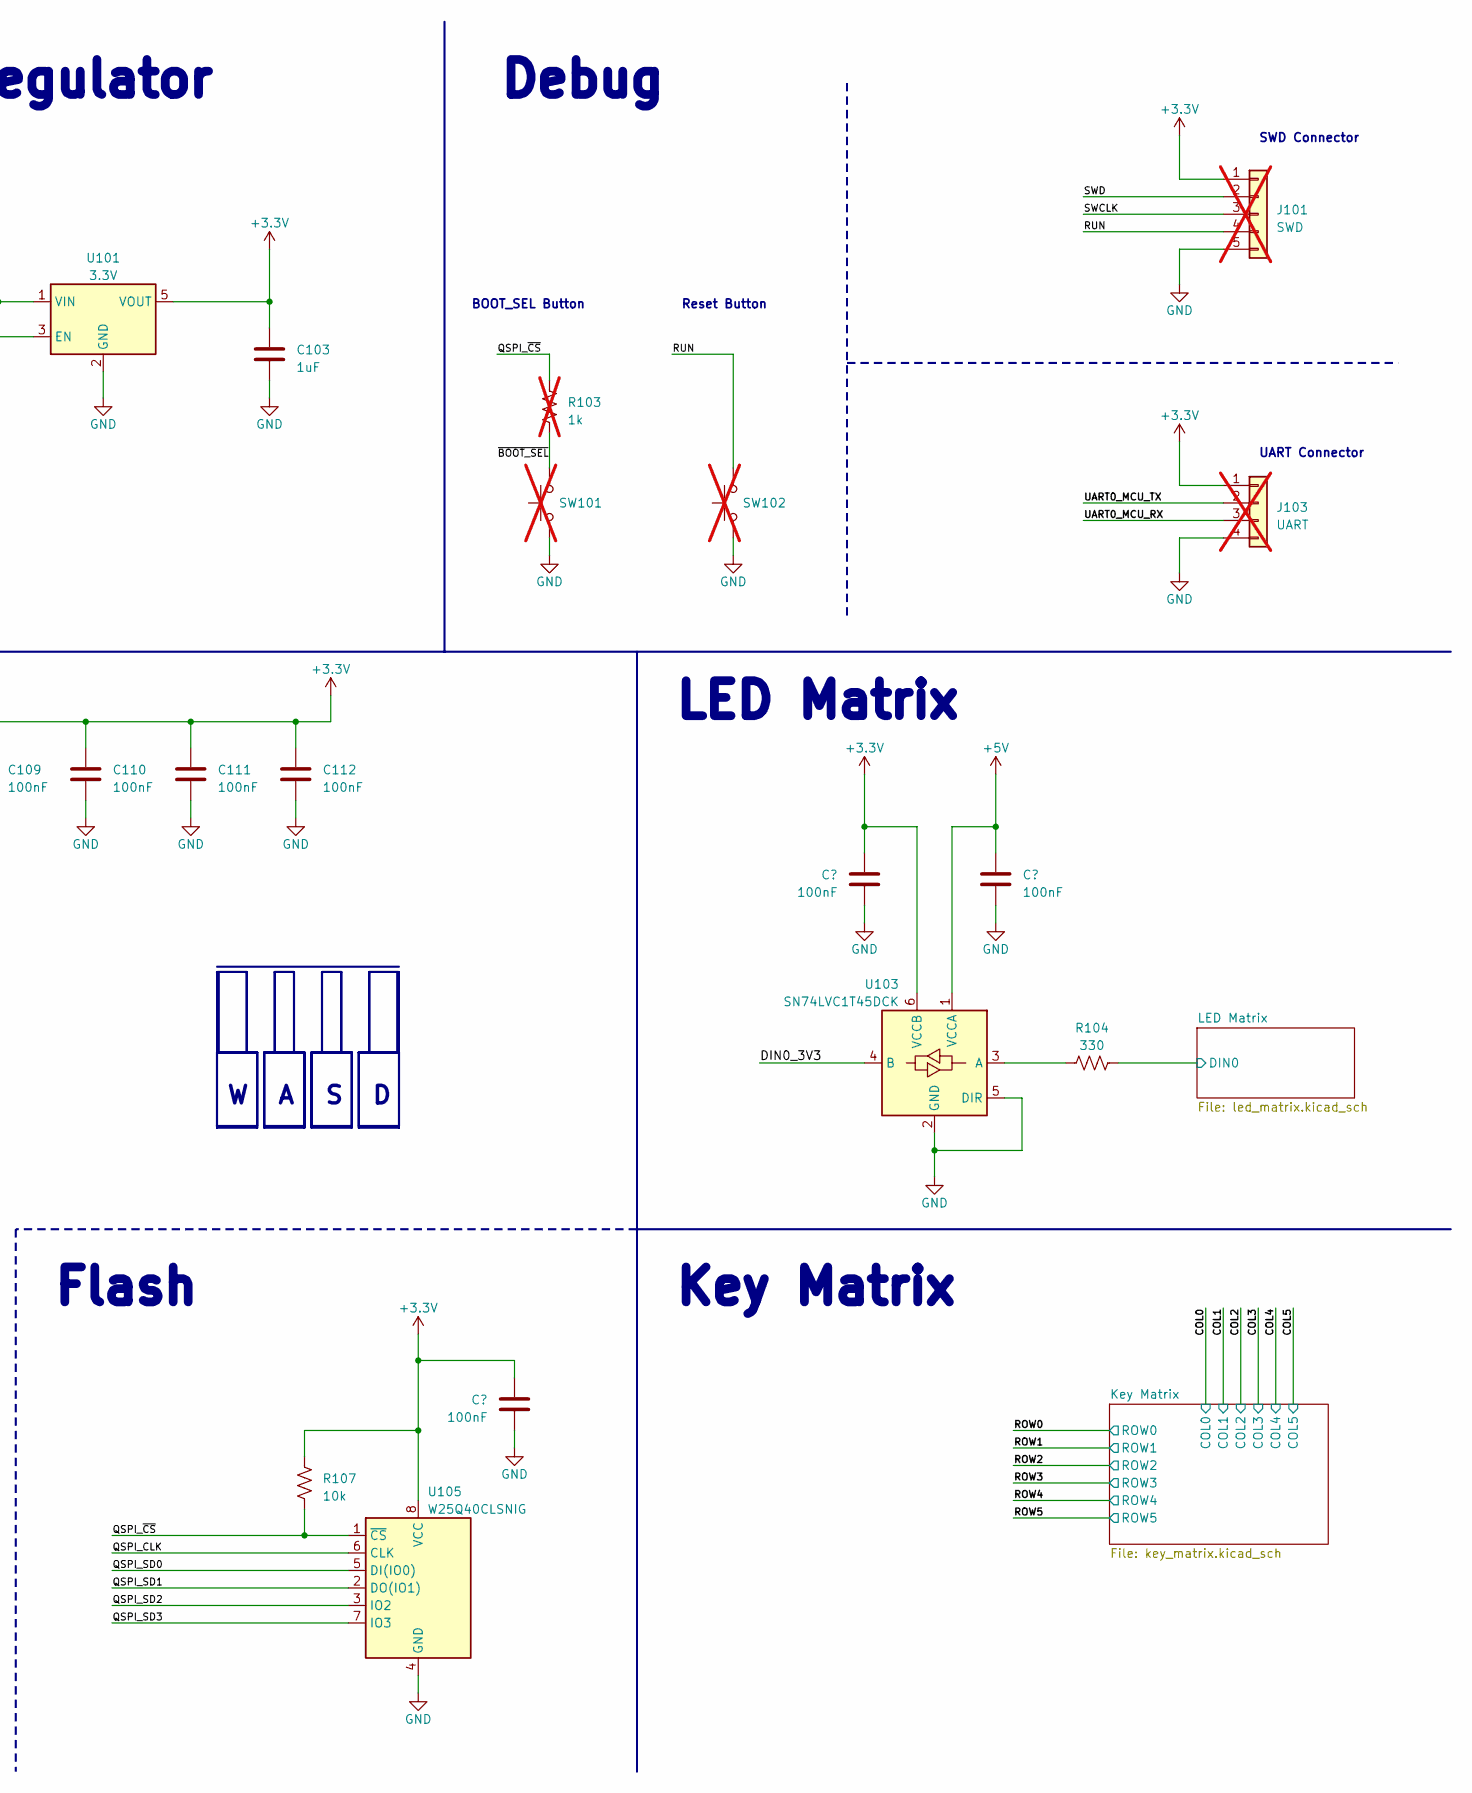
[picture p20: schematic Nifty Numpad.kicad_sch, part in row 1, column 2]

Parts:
C101: 10uF; C_0603_1608Metric; DigiKey PN 490-10475-1-ND
C102, C103, C115, C116: 1uF; C_0603_1608Metric; DigiKey PN 1276-6524-1-ND
C104, C105, C106, C107, C108, C109, C110, C111, C112, C113, C114, C117: 100nF; C_0603_1608Metric; DigiKey PN 1276-1006-1-ND
C118, C119: 27pF; C_0603_1608Metric; DigiKey PN 1276-2247-1-ND
H101, H102, H103, H104, H105: 6.00mm; MountingHole_6.0mm_ReducedCourtyard
J101: SWD; PinHeader_1x05_P2.54mm_Vertical; DigiKey PN 2057-PH1-05-UA-ND; not fitted
J102: USB-C; USB_C_Receptacle_GCT_USB4105-GF-A-060; DigiKey PN 2073-USB4105-GF-A-060CT-ND
J103: UART; PinHeader_1x04_P2.54mm_Vertical; DigiKey PN 2057-PH1-04-UA-ND; not fitted
R101, R102: 5.1k; R_0603_1608Metric; DigiKey PN CR0603-FX-5101ELFCT-ND
R103: 1k; R_0603_1608Metric; DigiKey PN RNCP0603FTD1K00CT-ND; not fitted
R104: 330; R_0603_1608Metric; DigiKey PN CR0603-FX-3300ELFCT-ND
R105, R106: 27; R_0603_1608Metric; DigiKey PN CR0603-FX-27R0ELFCT-ND
R107: 10k; R_0603_1608Metric; DigiKey PN RNCP0603FTD1K00CT-ND
R108: 1k; R_0603_1608Metric; DigiKey PN RNCP0603FTD1K00CT-ND
SW101, SW102: PTS636 SL43 SMTR LFS; SW-PUSH-6x3.5mm_CK-PTS636SL43x_HandSolder; DigiKey PN CKN12309-1-ND; not fitted
U101: 3.3V; SOT-353_SC-70-5; DigiKey PN 576-3215-1-ND
U102: CM1213A−02Sx; SOT-143; DigiKey PN CM1213A-02SROSCT-ND
U103: SN74LVC1T45DCK; SOT-363_SC-70-6; DigiKey PN 31-74LVC1T45DW-7CT-ND
U104: RP2040; QFN-56-1EP_7x7mm_P0.4mm_EP3.2x3.2mm; DigiKey PN 2648-SC0914(13)CT-ND
U105: W25Q40CLSNIG; SOIC-8_3.9x4.9mm_P1.27mm; DigiKey PN W25Q40CLSNIG-ND
Y101: ABLS-12.000MHZ-B4-T; Crystal_SMD_HC49-SD; DigiKey PN 535-10218-1-ND

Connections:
+3.3V: C103.1, C106.1, C107.1, C108.1, C109.1, C110.1, C111.1, C112.1, C113.1, C116.1, C117.1, J101.1, J103.1, R107.1, U101.5 (VOUT), U103.6 (VCCB), U104.1 (IOVDD), U104.10 (IOVDD), U104.22 (IOVDD), U104.33 (IOVDD), U104.42 (IOVDD), U104.43 (ADC_AVDD), U104.44 (VREG_IN), U104.48 (USB_VDD), U104.49 (IOVDD), U105.8 (VCC)
+5V: C101.1, C102.1, C114.1, J102.A4 (VBUS), J102.A9 (VBUS), J102.B4 (VBUS), J102.B9 (VBUS), U101.1 (VIN), U101.3 (EN), U102.4 (VP), U103.1 (VCCA); also elsewhere on the board
/COL0: U104.28 (GPIO17); also elsewhere on the board
/COL1: U104.29 (GPIO18); also elsewhere on the board
/COL2: U104.18 (GPIO15); also elsewhere on the board
/COL3: U104.16 (GPIO13); also elsewhere on the board
/COL4: U104.17 (GPIO14); also elsewhere on the board
/COL5: U104.15 (GPIO12); also elsewhere on the board
/DIN0_3V3: U103.4 (B), U104.30 (GPIO19)
/DVDD_1.1V: C104.1, C105.1, C115.1, U104.23 (DVDD), U104.45 (VREG_VOUT), U104.50 (DVDD)
/LED Matrix/DIN0: R104.2; also elsewhere on the board
/QSPI_CLK: U104.52 (QSPI_SCLK), U105.6 (CLK)
/QSPI_SD0: U104.53 (QSPI_SD0), U105.5 (DI(IO0))
/QSPI_SD1: U104.55 (QSPI_SD1), U105.2 (DO(IO1))
/QSPI_SD2: U104.54 (QSPI_SD2), U105.3 (IO2)
/QSPI_SD3: U104.51 (QSPI_SD3), U105.7 (IO3)
/QSPI_~CS: R103.2, R107.2, U104.56 (QSPI_SS), U105.1 (~CS)
/ROW0: U104.31 (GPIO20); also elsewhere on the board
/ROW1: U104.32 (GPIO21); also elsewhere on the board
/ROW2: U104.34 (GPIO22); also elsewhere on the board
/ROW3: U104.35 (GPIO23); also elsewhere on the board
/ROW4: U104.36 (GPIO24); also elsewhere on the board
/ROW5: U104.37 (GPIO25); also elsewhere on the board
/RUN: J101.4, SW102.2, U104.26 (RUN)
/SWCLK: J101.3, U104.24 (SWCLK)
/SWD: J101.2, U104.25 (SWD)
/UART0_MCU_RX: J103.3, U104.3 (GPIO1)
/UART0_MCU_TX: J103.2, U104.2 (GPIO0)
/USB_DN: J102.A7 (D-), J102.B7 (D-), R106.1, U102.2 (CH1)
/USB_DP: J102.A6 (D+), J102.B6 (D+), R105.1, U102.3 (CH2)
/USB_RP_DN: R106.2, U104.46 (USB_DM)
/USB_RP_DP: R105.2, U104.47 (USB_DP)
/~BOOT_SEL: R103.1, SW101.2
GND: C101.2, C102.2, C103.2, C104.2, C105.2, C106.2, C107.2, C108.2, C109.2, C110.2, C111.2, C112.2, C113.2, C114.2, C115.2, C116.2, C117.2, C118.2, C119.2, J101.5, J102.A1 (GND), J102.A12 (GND), J102.B1 (GND), J102.B12 (GND), J102.S1 (SHIELD), J103.4, R101.2, R102.2, SW101.1, SW102.1, U101.2 (GND), U102.1 (VN), U103.2 (GND), U103.5 (DIR), U104.19 (TESTEN), U104.57 (GND), U105.4 (GND); also elsewhere on the board
unnamed: C119.1, R108.1, Y101.2
unnamed: J102.A5 (CC1), R102.1
unnamed: J102.B5 (CC2), R101.1
unnamed: R104.1, U103.3 (A)
unnamed: C118.1, U104.20 (XIN), Y101.1
unnamed: R108.2, U104.21 (XOUT)

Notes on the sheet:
Place close to pin 45
Distribute 100nF caps to power pins
Place close to pin 44
USB In
UART Connector
Debug
12 MHz Clock
Flash
SWD Connector
MCU
BOOT_SEL Button
Mounting Holes
Key Matrix
LED Matrix
Reset Button
3.3V Regulator

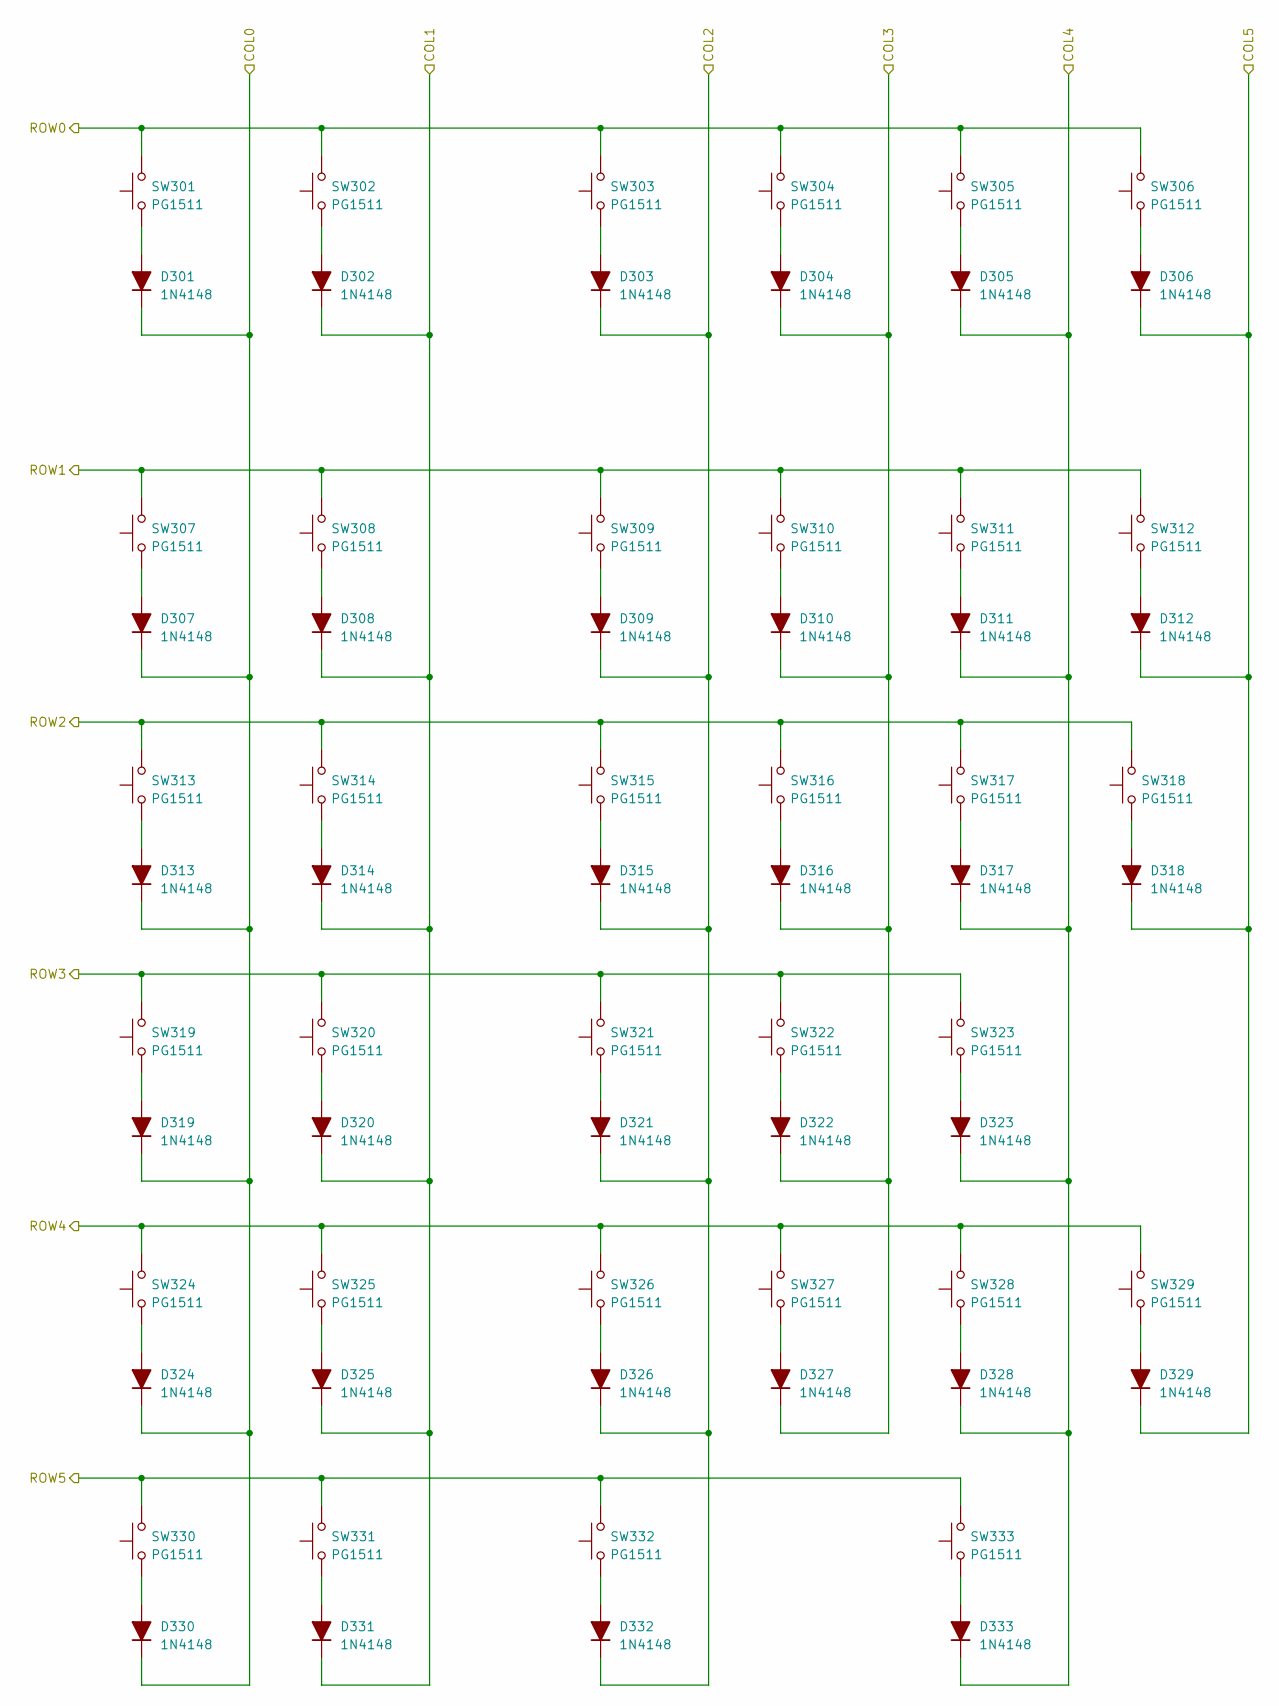
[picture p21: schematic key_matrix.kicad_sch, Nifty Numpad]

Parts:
D301, D302, D303, D304, D305, D306, D307, D308, D309, D310, D311, D312, D313, D314, D315, D316, D317, D318, D319, D320, D321, D322, D323, D324, D325, D326, D327, D328, D329, D330, D331, D332, D333: 1N4148; D_SOD-123; DigiKey PN 4530-1N4148WCT-ND
SW301, SW302, SW303, SW304, SW305, SW306, SW307, SW308, SW309, SW310, SW311, SW312, SW313, SW314, SW315, SW316, SW317, SW319, SW320, SW321, SW322, SW323, SW324, SW325, SW326, SW327, SW328, SW330, SW331, SW333: PG1511; SW_Hotswap_Kailh_MX_1.00u; LCSC C5156480
SW318, SW329: PG1511; SW_Hotswap_Kailh_MX_2.00u_90deg; LCSC C5156480
SW332: PG1511; SW_Hotswap_Kailh_MX_2.00u; LCSC C5156480

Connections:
/COL0: D301.1 (K), D307.1 (K), D313.1 (K), D319.1 (K), D324.1 (K), D330.1 (K); also elsewhere on the board
/COL1: D302.1 (K), D308.1 (K), D314.1 (K), D320.1 (K), D325.1 (K), D331.1 (K); also elsewhere on the board
/COL2: D303.1 (K), D309.1 (K), D315.1 (K), D321.1 (K), D326.1 (K), D332.1 (K); also elsewhere on the board
/COL3: D304.1 (K), D310.1 (K), D316.1 (K), D322.1 (K), D327.1 (K); also elsewhere on the board
/COL4: D305.1 (K), D311.1 (K), D317.1 (K), D323.1 (K), D328.1 (K), D333.1 (K); also elsewhere on the board
/COL5: D306.1 (K), D312.1 (K), D318.1 (K), D329.1 (K); also elsewhere on the board
/ROW0: SW301.2, SW302.2, SW303.2, SW304.2, SW305.2, SW306.2; also elsewhere on the board
/ROW1: SW307.2, SW308.2, SW309.2, SW310.2, SW311.2, SW312.2; also elsewhere on the board
/ROW2: SW313.2, SW314.2, SW315.2, SW316.2, SW317.2, SW318.2; also elsewhere on the board
/ROW3: SW319.2, SW320.2, SW321.2, SW322.2, SW323.2; also elsewhere on the board
/ROW4: SW324.2, SW325.2, SW326.2, SW327.2, SW328.2, SW329.2; also elsewhere on the board
/ROW5: SW330.2, SW331.2, SW332.2, SW333.2; also elsewhere on the board
unnamed: D301.2 (A), SW301.1
unnamed: D302.2 (A), SW302.1
unnamed: D303.2 (A), SW303.1
unnamed: D304.2 (A), SW304.1
unnamed: D305.2 (A), SW305.1
unnamed: D306.2 (A), SW306.1
unnamed: D307.2 (A), SW307.1
unnamed: D308.2 (A), SW308.1
unnamed: D309.2 (A), SW309.1
unnamed: D310.2 (A), SW310.1
unnamed: D311.2 (A), SW311.1
unnamed: D312.2 (A), SW312.1
unnamed: D313.2 (A), SW313.1
unnamed: D314.2 (A), SW314.1
unnamed: D315.2 (A), SW315.1
unnamed: D316.2 (A), SW316.1
unnamed: D317.2 (A), SW317.1
unnamed: D318.2 (A), SW318.1
unnamed: D319.2 (A), SW319.1
unnamed: D320.2 (A), SW320.1
unnamed: D321.2 (A), SW321.1
unnamed: D322.2 (A), SW322.1
unnamed: D323.2 (A), SW323.1
unnamed: D324.2 (A), SW324.1
unnamed: D325.2 (A), SW325.1
unnamed: D326.2 (A), SW326.1
unnamed: D327.2 (A), SW327.1
unnamed: D328.2 (A), SW328.1
unnamed: D329.2 (A), SW329.1
unnamed: D330.2 (A), SW330.1
unnamed: D331.2 (A), SW331.1
unnamed: D332.2 (A), SW332.1
unnamed: D333.2 (A), SW333.1

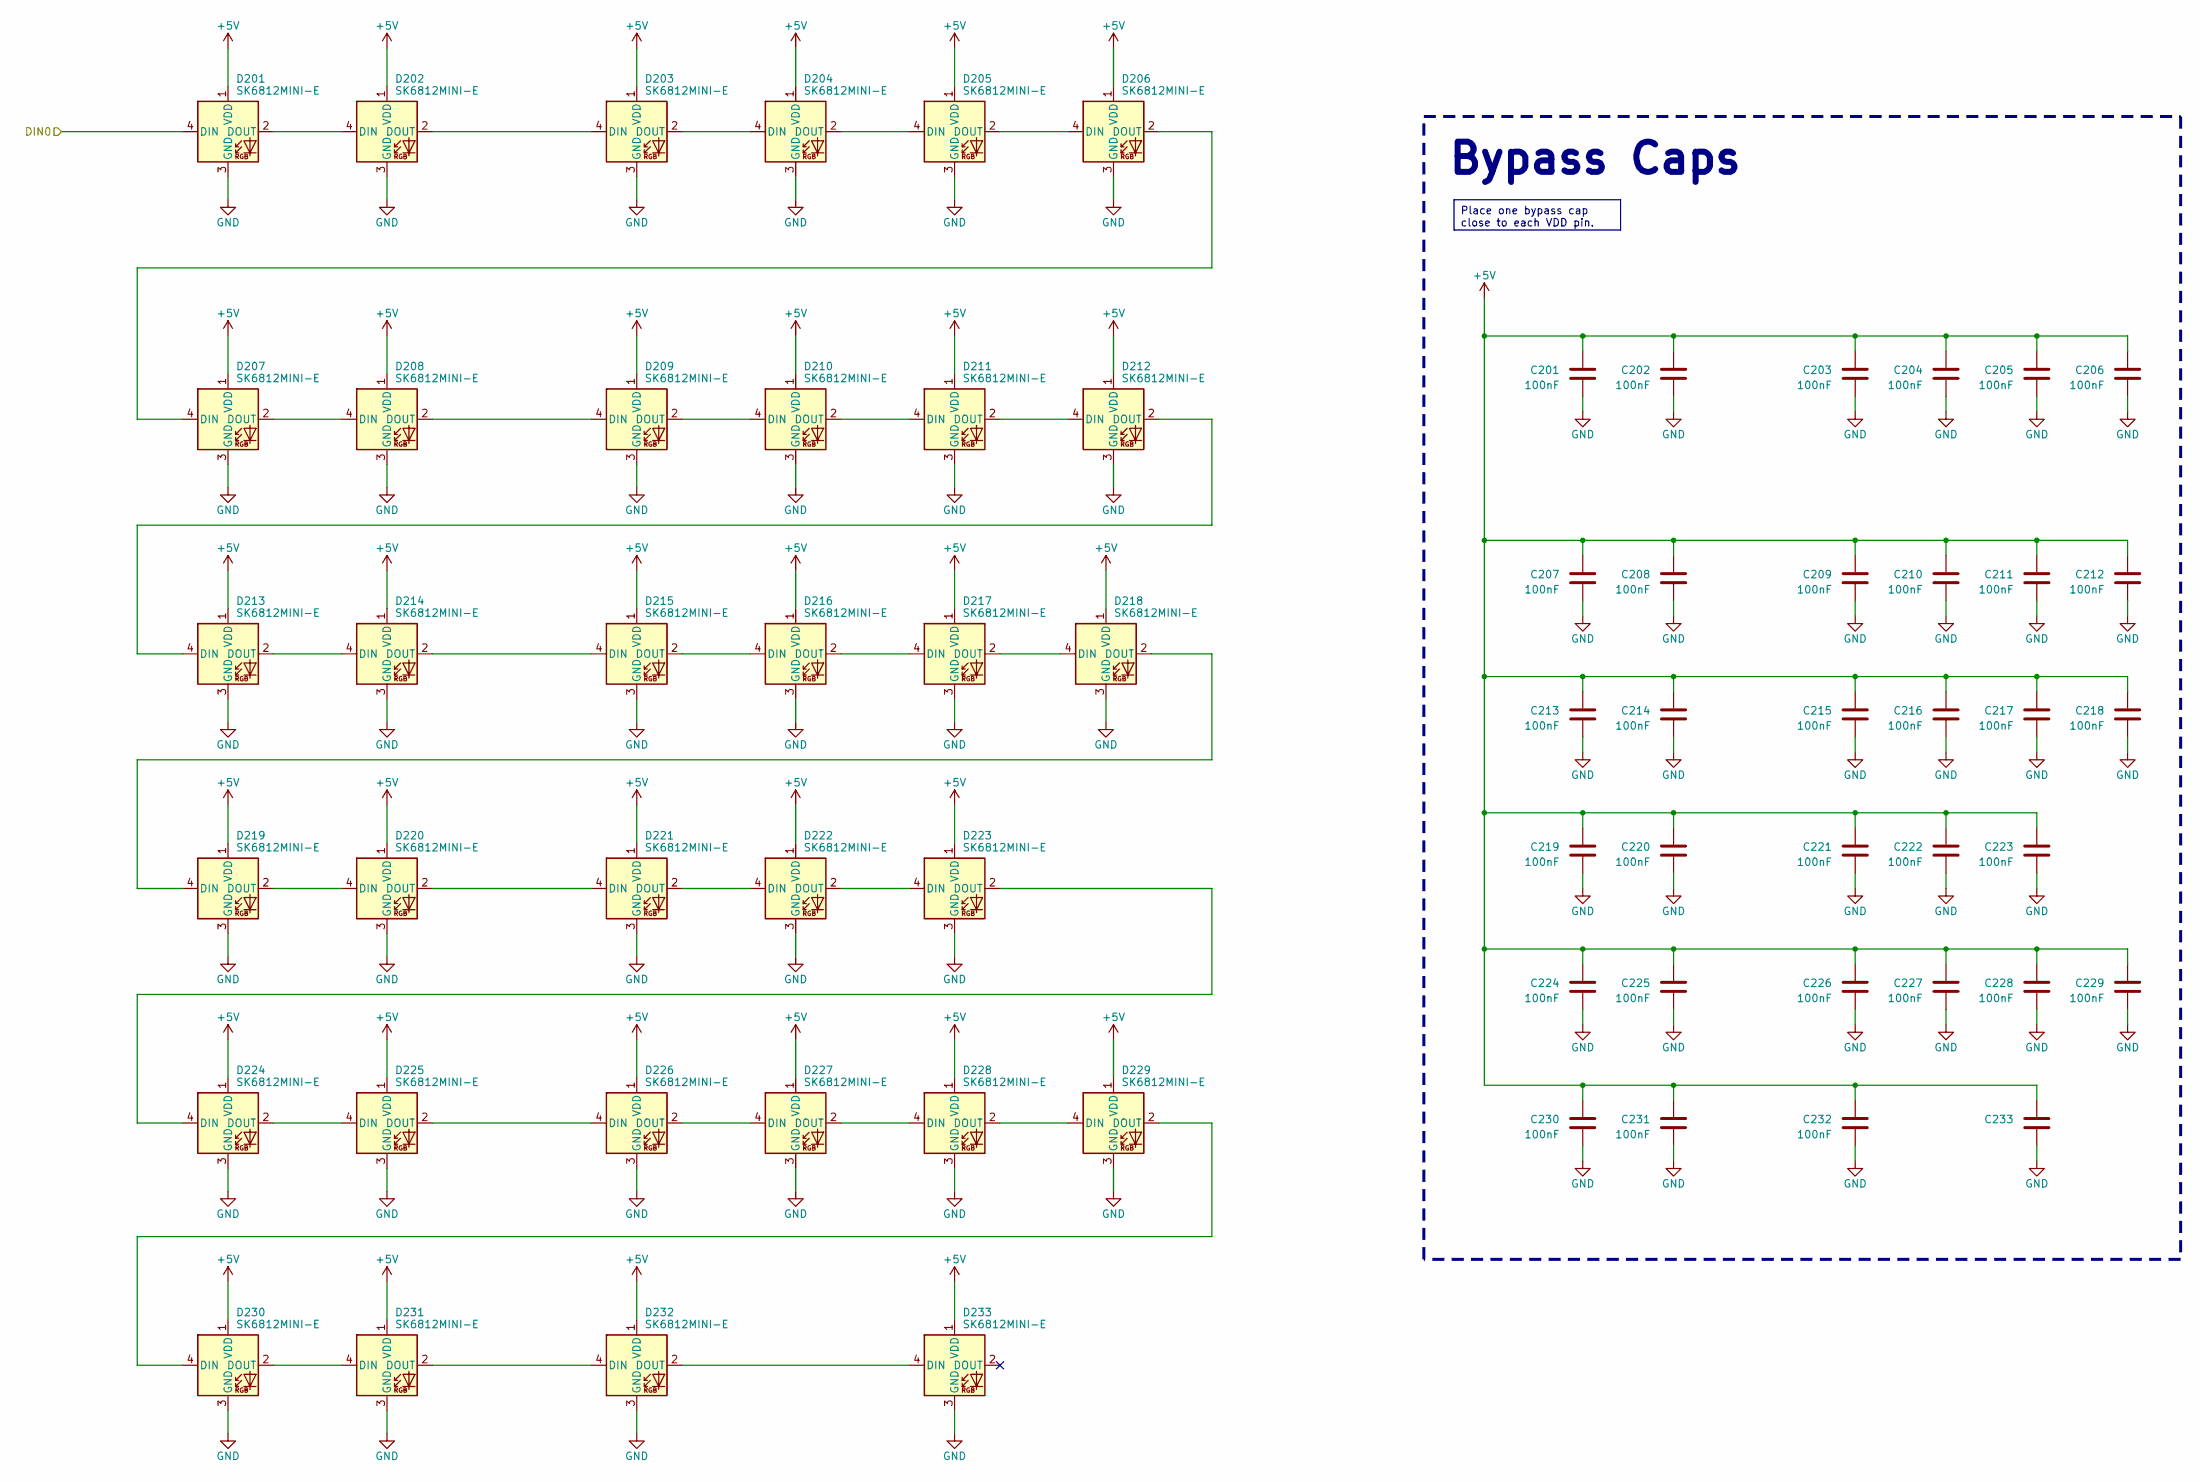
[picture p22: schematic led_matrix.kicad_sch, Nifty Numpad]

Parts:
C201, C202, C203, C204, C205, C206, C207, C208, C209, C210, C211, C212, C213, C214, C215, C216, C217, C218, C219, C220, C221, C222, C223, C224, C225, C226, C227, C228, C229, C230, C231, C232, C233: 100nF; C_0603_1608Metric; DigiKey PN 1276-1006-1-ND
D201, D202, D203, D204, D205, D206, D207, D208, D209, D210, D211, D212, D213, D214, D215, D216, D217, D218, D219, D220, D221, D222, D223, D224, D225, D226, D227, D228, D229, D230, D231, D232, D233: SK6812MINI-E; LED_SK6812MINI-E_3.2x2.8mm; DigiKey PN 1528-4960-ND

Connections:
+5V: C201.1, C202.1, C203.1, C204.1, C205.1, C206.1, C207.1, C208.1, C209.1, C210.1, C211.1, C212.1, C213.1, C214.1, C215.1, C216.1, C217.1, C218.1, C219.1, C220.1, C221.1, C222.1, C223.1, C224.1, C225.1, C226.1, C227.1, C228.1, C229.1, C230.1, C231.1, C232.1, C233.1, D201.1 (VDD), D202.1 (VDD), D203.1 (VDD), D204.1 (VDD), D205.1 (VDD), D206.1 (VDD), D207.1 (VDD), D208.1 (VDD), D209.1 (VDD), D210.1 (VDD), D211.1 (VDD), D212.1 (VDD), D213.1 (VDD), D214.1 (VDD), D215.1 (VDD), D216.1 (VDD), D217.1 (VDD), D218.1 (VDD), D219.1 (VDD), D220.1 (VDD), D221.1 (VDD), D222.1 (VDD), D223.1 (VDD), D224.1 (VDD), D225.1 (VDD), D226.1 (VDD), D227.1 (VDD), D228.1 (VDD), D229.1 (VDD), D230.1 (VDD), D231.1 (VDD), D232.1 (VDD), D233.1 (VDD); also elsewhere on the board
/LED Matrix/DIN0: D201.4 (DIN); also elsewhere on the board
GND: C201.2, C202.2, C203.2, C204.2, C205.2, C206.2, C207.2, C208.2, C209.2, C210.2, C211.2, C212.2, C213.2, C214.2, C215.2, C216.2, C217.2, C218.2, C219.2, C220.2, C221.2, C222.2, C223.2, C224.2, C225.2, C226.2, C227.2, C228.2, C229.2, C230.2, C231.2, C232.2, C233.2, D201.3 (GND), D202.3 (GND), D203.3 (GND), D204.3 (GND), D205.3 (GND), D206.3 (GND), D207.3 (GND), D208.3 (GND), D209.3 (GND), D210.3 (GND), D211.3 (GND), D212.3 (GND), D213.3 (GND), D214.3 (GND), D215.3 (GND), D216.3 (GND), D217.3 (GND), D218.3 (GND), D219.3 (GND), D220.3 (GND), D221.3 (GND), D222.3 (GND), D223.3 (GND), D224.3 (GND), D225.3 (GND), D226.3 (GND), D227.3 (GND), D228.3 (GND), D229.3 (GND), D230.3 (GND), D231.3 (GND), D232.3 (GND), D233.3 (GND); also elsewhere on the board
unnamed: D201.2 (DOUT), D202.4 (DIN)
unnamed: D202.2 (DOUT), D203.4 (DIN)
unnamed: D203.2 (DOUT), D204.4 (DIN)
unnamed: D204.2 (DOUT), D205.4 (DIN)
unnamed: D205.2 (DOUT), D206.4 (DIN)
unnamed: D206.2 (DOUT), D207.4 (DIN)
unnamed: D207.2 (DOUT), D208.4 (DIN)
unnamed: D208.2 (DOUT), D209.4 (DIN)
unnamed: D209.2 (DOUT), D210.4 (DIN)
unnamed: D210.2 (DOUT), D211.4 (DIN)
unnamed: D211.2 (DOUT), D212.4 (DIN)
unnamed: D212.2 (DOUT), D213.4 (DIN)
unnamed: D213.2 (DOUT), D214.4 (DIN)
unnamed: D214.2 (DOUT), D215.4 (DIN)
unnamed: D215.2 (DOUT), D216.4 (DIN)
unnamed: D216.2 (DOUT), D217.4 (DIN)
unnamed: D217.2 (DOUT), D218.4 (DIN)
unnamed: D218.2 (DOUT), D219.4 (DIN)
unnamed: D219.2 (DOUT), D220.4 (DIN)
unnamed: D220.2 (DOUT), D221.4 (DIN)
unnamed: D221.2 (DOUT), D222.4 (DIN)
unnamed: D222.2 (DOUT), D223.4 (DIN)
unnamed: D223.2 (DOUT), D224.4 (DIN)
unnamed: D224.2 (DOUT), D225.4 (DIN)
unnamed: D225.2 (DOUT), D226.4 (DIN)
unnamed: D226.2 (DOUT), D227.4 (DIN)
unnamed: D227.2 (DOUT), D228.4 (DIN)
unnamed: D228.2 (DOUT), D229.4 (DIN)
unnamed: D229.2 (DOUT), D230.4 (DIN)
unnamed: D230.2 (DOUT), D231.4 (DIN)
unnamed: D231.2 (DOUT), D232.4 (DIN)
unnamed: D232.2 (DOUT), D233.4 (DIN)

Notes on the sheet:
Place one bypass cap close to each VDD pin.
Bypass Caps

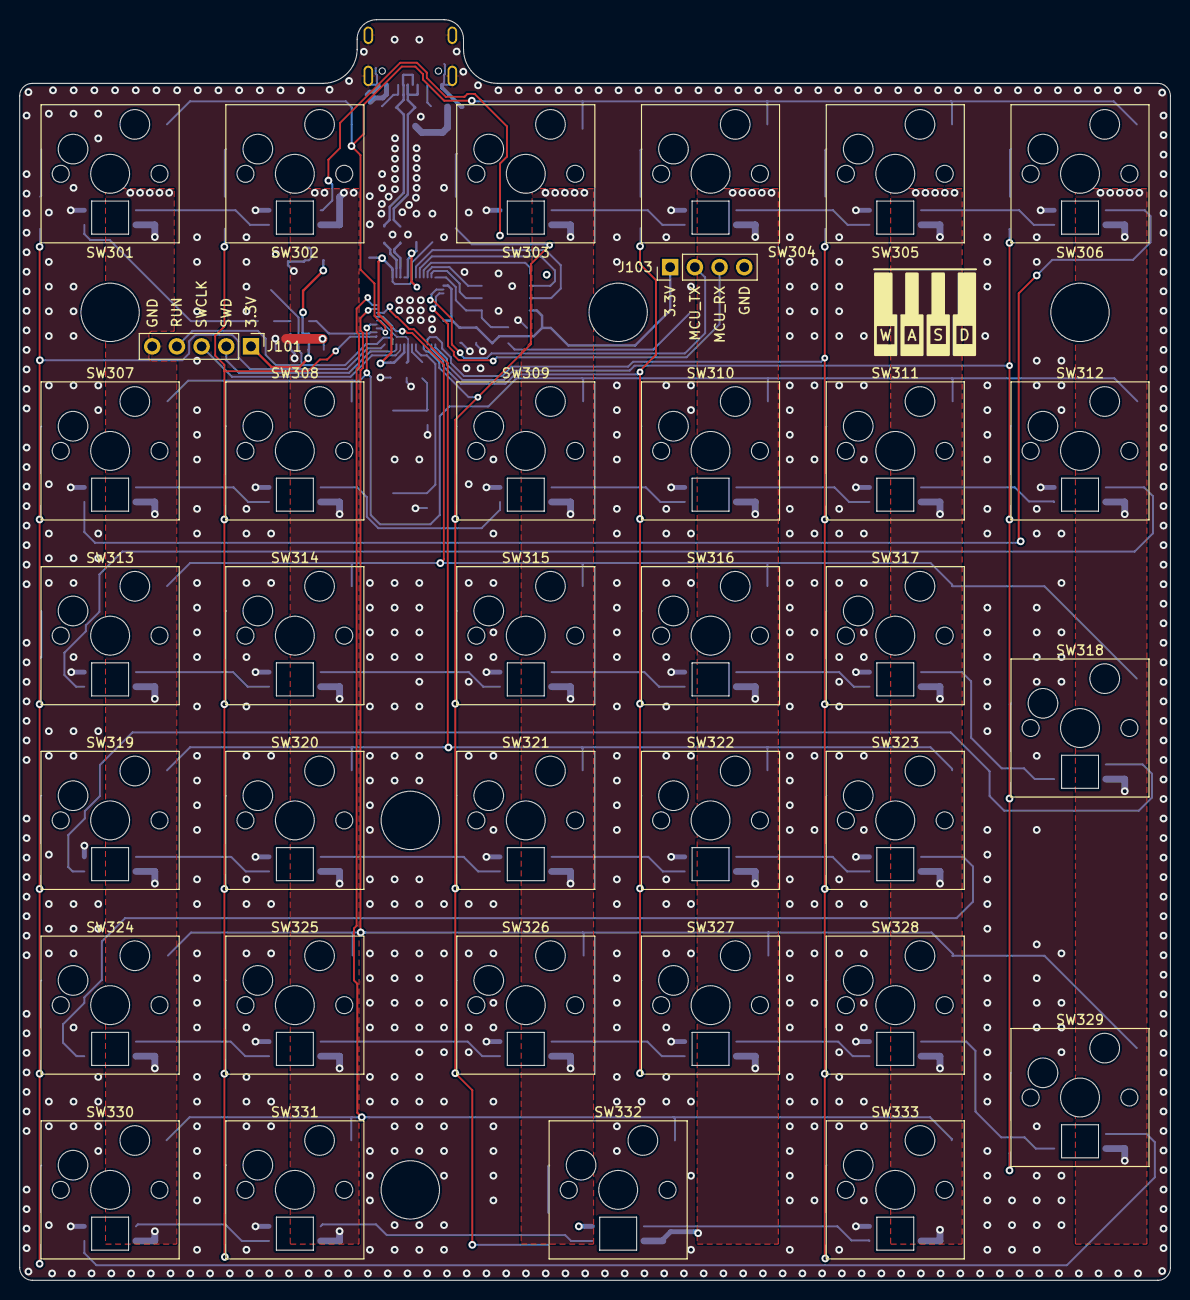
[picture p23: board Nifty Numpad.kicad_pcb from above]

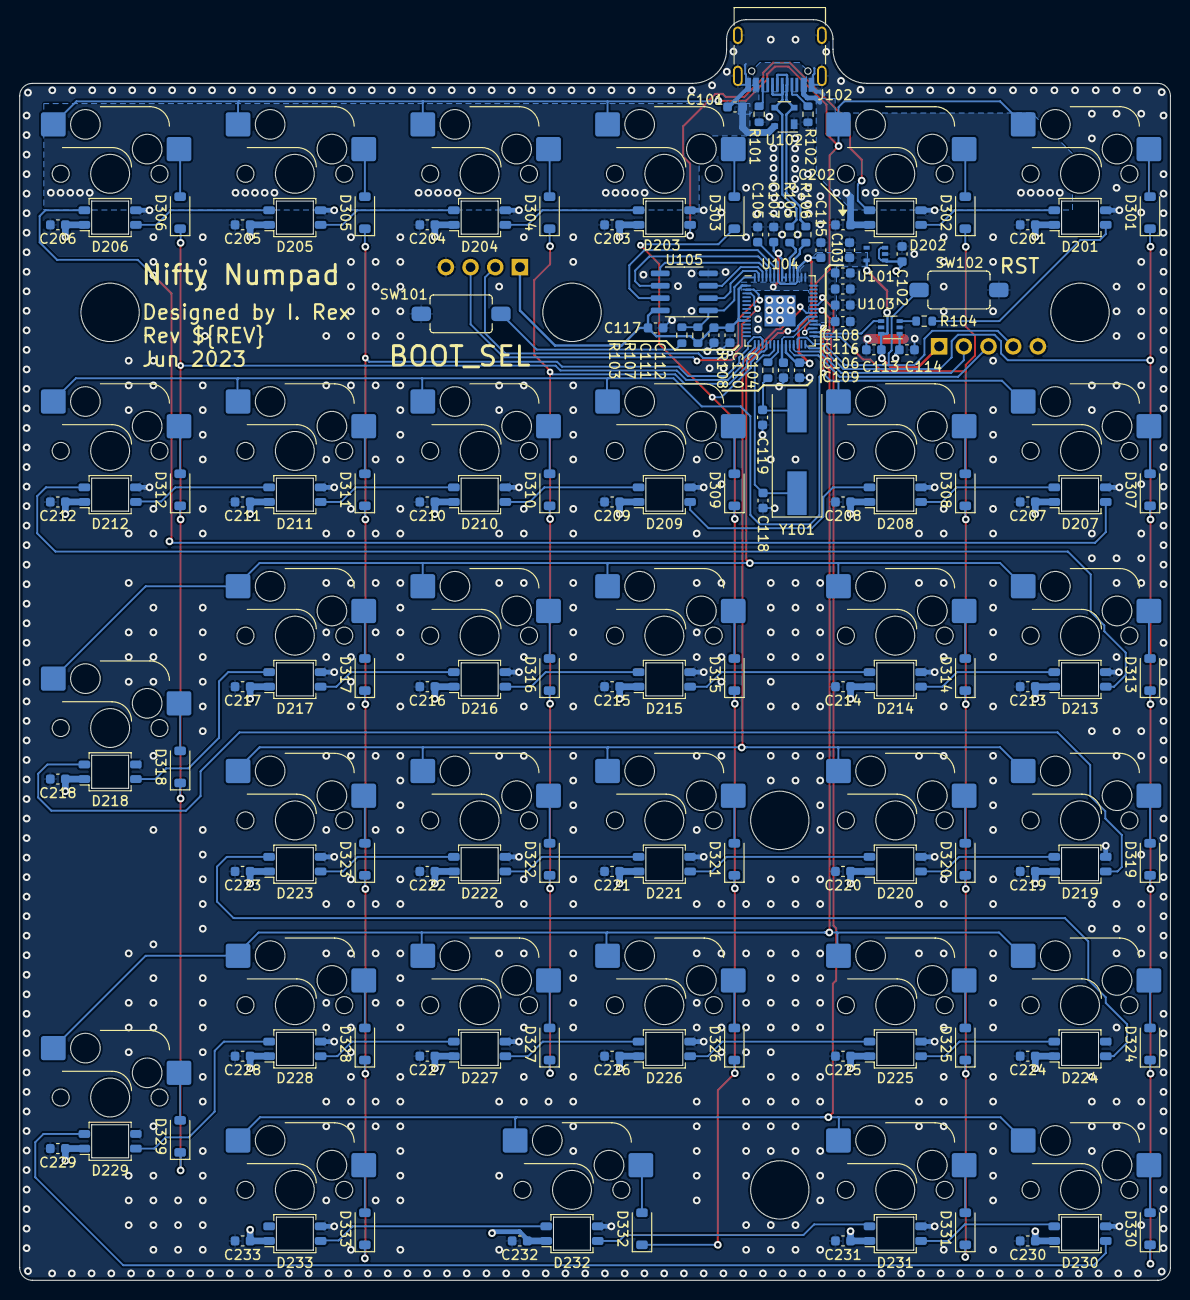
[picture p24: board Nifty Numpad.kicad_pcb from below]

Board: 2 copper layers, 118.4 x 129.7 mm, 175 parts (135 on the bottom side), 105 nets.

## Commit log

2023-07-28 Moved signature to inside base and added shadow line between top and base
    [Base.3mf, Base.stl, Top.3mf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]
2023-07-30 Fixed LED rotation, beefed up standoffs, added docs
    [BOM.csv, Kailh Hotswap MX.step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]
2023-10-07 Added PCB files for the mounting plate
    [Nifty Numpad-B_Cu.gbr, Nifty Numpad-B_Mask.gbr, Nifty Numpad-B_Paste.gbr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]
2023-10-07 Updated plate to use pan head instead of flathead screws
    [Base.stl, Plate Drawing.dxf, Top.stl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]
